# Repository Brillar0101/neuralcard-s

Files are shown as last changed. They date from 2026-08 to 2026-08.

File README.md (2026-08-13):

# NeuralCard







A business card that runs a neural network.

> This is the sponsorship build, a fork of
> [NeuralCard](https://github.com/Brillar0101/NeuralCard) prepared for assembly by
> PCBWay. The BOM has been rewritten from JLCPCB and LCSC part codes into
> manufacturer part numbers PCBWay can quote, with approved alternates where a swap
> is safe and do-not-substitute rules where it is not. Every part in the schematic
> and the board now carries `Alt MPN`, `Alt Mfr`, and `Sourcing` fields alongside
> the existing MPN. See [`docs/SOURCING.md`](docs/SOURCING.md) for the reasoning and
> [`fab/BOM_PCBWay.csv`](fab/BOM_PCBWay.csv) for the order-ready BOM. No copper
> changed, and DRC and ERC still pass clean.

It is a credit-card-sized PCB, 85.6 by 54 mm, carrying an ESP32-S3, a 6-axis
IMU, and 24 LEDs laid out as the network it actually runs: 6 input neurons,
8 hidden, 10 output. You hold the card, draw a digit in the air, and the LEDs
light with the real activations as inference runs. Brightest output neuron
wins.

The front artwork is the network diagram. The synapse lines are drawn at three
stroke weights, the way a trained model's weights differ. There is also an NFC
tag with a coil antenna etched into the copper, so tapping a phone opens
[princetekki.com/card](https://www.princetekki.com/card) and offers a vCard.
That works with a dead battery, or no battery at all, because the phone's own
field powers the tag.

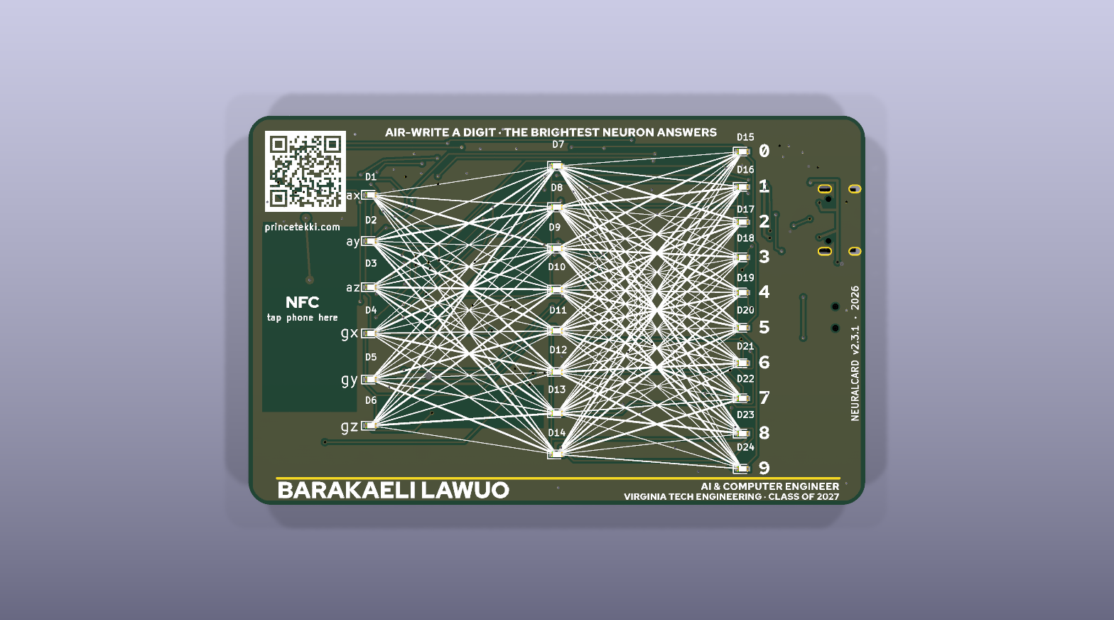
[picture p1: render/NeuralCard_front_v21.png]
front

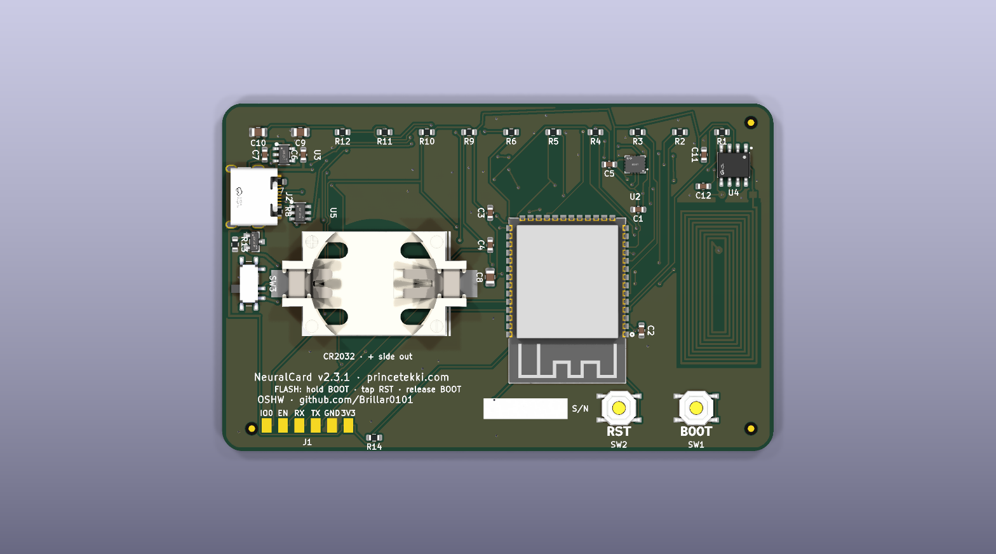
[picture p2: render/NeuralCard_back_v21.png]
back


## Repository layout

| Path | What's in it |
|---|---|
| `hardware/` | KiCad 10 project: schematic, board, custom symbol and footprint libraries, 3D models |
| `fab/` | Manufacturing outputs: gerber zip, drill files, pick-and-place, and two BOMs: `BOM_PCBWay.csv` (MPN-based, for this build) and `BOM_JLCPCB.csv` (upstream, LCSC codes) |
| `firmware/` | ESP-IDF project. Charlieplex driver, IMU driver, gesture recorder. Builds today. |
| `docs/` | Design rationale, component sourcing, datasheet findings, DRC history, audits, FAQ |
| `render/` | The board renders used above |
| `CHANGELOG.md` | Revision history, newest first |

Start with [`docs/DESIGN.md`](docs/DESIGN.md) for why the board is shaped the
way it is, [`docs/FAQ.md`](docs/FAQ.md) for the questions people actually ask,
and [`docs/drc/README.md`](docs/drc/README.md) for the verification trail.

## Hardware

An ESP32-S3-WROOM-1-N8R2 does the thinking and runs the inference. An
LSM6DS3TR-C accelerometer and gyro sits on I2C, and its six axes map one to one
onto the six input neurons. The 24 red LEDs are charlieplexed across 6 GPIO
with software PWM for the glow.

For the business-card half there is an ST25DV04K dynamic NFC tag with a 9-turn
coil in the copper, tuned by a single external cap (C12) against the chip's
internal capacitance.

USB-C arrived in v2.3. The S3 has native USB, so a plain cable flashes the
board and gives a serial console without an adapter. A USBLC6-2SC6 protects the
data pair.

Power comes from either a CR2032 through a real slide switch (SW3) or USB 5 V
through an ME6211 LDO. A P-FET (Q1) disconnects the cell whenever USB is
present, so the board can never try to charge a cell that is not rechargeable.

Two layers, ground poured on both sides and stitched. Every net is one
connected cluster.

## How it's wired

Power first. Two sources that can never fight each other.

```mermaid
flowchart LR
    USB["USB-C · J2<br/>5 V VBUS"] --> LDO["U3 · ME6211<br/>3.3 V LDO"]
    BT1["BT1<br/>CR2032 · 3.0 V"] -->|VBAT| SW3{{"SW3 · MSK12C02<br/>SPDT slide"}}
    SW3 -->|"ON"| Q1{{"Q1 · AO3401A<br/>P-FET isolation"}}
    SW3 -.->|"OFF"| NC(["open throw"])
    LDO --> RAIL[["+3V3 rail"]]
    LDO -.->|"VBUS present<br/>gates the cell off"| Q1
    Q1 --> RAIL
    RAIL --> U1["ESP32-S3"]
    RAIL --> U2["LSM6DS3TR-C"]
    RAIL --> U4["ST25DV04K"]
    RAIL --> LEDS["24 LEDs<br/>charlieplexed"]

    classDef src fill:#F0AB00,stroke:#795600,color:#151515
    classDef sw fill:#0066CC,stroke:#003366,color:#FFFFFF
    classDef rail fill:#009596,stroke:#005F60,color:#FFFFFF
    classDef load fill:#F0F0F0,stroke:#8A8D90,color:#151515
    classDef off fill:#FFFFFF,stroke:#C9190B,color:#C9190B,stroke-dasharray:4 3
    class USB,BT1 src
    class SW3,Q1,LDO sw
    class RAIL rail
    class U1,U2,U4,LEDS load
    class NC off
```

Then data. USB-C carries both power and programming. NFC is independent of
both and needs no power of its own.

```mermaid
flowchart LR
    HOST(["laptop"]) -->|"USB-C · D+/D-"| ESD["U5 · USBLC6<br/>ESD array"]
    ESD -->|"native USB-Serial-JTAG"| U1["ESP32-S3"]
    U1 <-->|I2C| U2["IMU"]
    U1 <-->|I2C| U4["NFC tag"]
    U2 -.->|"motion interrupt"| U1
    U4 -.->|"field-detect GPO"| U1
    PHONE(["phone"]) -.->|"13.56 MHz field<br/>powers the tag"| U4
    U1 --> LEDS["24 LEDs"]

    classDef ext fill:#F0AB00,stroke:#795600,color:#151515
    classDef chip fill:#0066CC,stroke:#003366,color:#FFFFFF
    classDef out fill:#3E8635,stroke:#1F4D19,color:#FFFFFF
    class HOST,PHONE ext
    class ESD,U1,U2,U4 chip
    class LEDS out
```

And inference. The six IMU axes feed the six input neurons, and the LEDs at
each node light with the real activations as the network runs.

```mermaid
flowchart LR
    IMU["LSM6DS3TR-C<br/>ax ay az · gx gy gz"] --> IN["INPUT<br/><b>6 neurons</b>"]
    IN --> HID["HIDDEN<br/><b>8 neurons</b>"]
    HID --> OUT["OUTPUT<br/><b>10 neurons</b><br/>digits 0-9"]
    OUT --> GUESS(["brightest neuron<br/>= the guess"])

    classDef sensor fill:#F0AB00,stroke:#795600,color:#151515
    classDef layer fill:#0066CC,stroke:#003366,color:#FFFFFF
    classDef out fill:#5752D1,stroke:#2A265F,color:#FFFFFF
    classDef result fill:#3E8635,stroke:#1F4D19,color:#FFFFFF
    class IMU sensor
    class IN,HID layer
    class OUT out
    class GUESS result
```

All 24 LEDs run from 6 GPIO by charlieplexing. That is why there are 6
current-limiting resistors rather than 24, and why the display works on a coin
cell at all: only one LED is ever actually lit.

## Firmware

`firmware/` is an ESP-IDF project that builds today. It has the charlieplex
driver, with the LED-to-pin mapping extracted from the board netlist rather
than guessed, the LSM6DS3 driver, and a motion-triggered gesture recorder that
prints labelled CSV over the USB-C console. That recorder is how you build a
training set.

```
cd firmware && idf.py set-target esp32s3 && idf.py build && idf.py flash monitor
```

The neural network itself is deliberately not in the repo yet: it has to be
trained on gestures recorded from real hands, which needs assembled boards.
See [`firmware/README.md`](firmware/README.md).

## Ordering

Everything a fab needs is in `fab/`: `NeuralCard_gerbers.zip` (gerbers +
drill), `NeuralCard-cpl.csv` (placements), and a BOM. Use
`BOM_PCBWay.csv` for this build, which carries manufacturer part numbers,
approved alternates, and per-line substitution rules. `BOM_JLCPCB.csv` is the
upstream file and is keyed to LCSC codes instead.

Build spec: 2 layers, 1.6 mm thickness, green soldermask, HASL. That is the
cheap prototype configuration, currently about $2 for five boards.

Two finish options are worth knowing about if you ever make a batch to hand
out. At 0.8 mm the board feels like a card instead of a circuit board. With
ENIG, the hairline under the name comes out gold, since it is a mask opening
over the ground pour and plates with whatever finish you pick. Both cost more.
Neither changes the gerbers, so they are order-time choices.

**Two build routes:**

Hand assembly means ordering bare boards plus a solder-paste stencil and
buying parts from LCSC. It is the cheapest route, and the stencil is what makes
the LGA-14 IMU tractable with hot air.

Factory assembly means turnkey PCBA on both sides. It adds roughly $100 of fixed
setup and feeder cost at a typical prototype house, so it only pays off around 30
boards or more. This build is being assembled by PCBWay under sponsorship, so see
[`docs/SOURCING.md`](docs/SOURCING.md) for how the parts are actually bought.

Two BOM notes. C12, the NFC tuning cap, ships as 68 pF and should be retuned
against the coil once it exists. Read range is the practical test. The NFC chip
is ST25DV04KC-IE6S3, which is the active part. The older ST25DV04K-IER6S3 is
marked not recommended for new designs but is still widely stocked, and it is
listed as the approved fallback: same package, same pinout, same function.

## Status

The hardware is done and verified at v2.3.1: DRC reports 0 violations and 0
unconnected, ERC is clean, every net is a single connected cluster, and the
footprints have been checked against manufacturer datasheets. It has never been
fabricated. These files would produce the first physical boards.

The firmware scaffold builds. Drivers and gesture capture work. The trained
model is the remaining piece, and it needs assembled boards before it can
exist.

So today the card is a very elaborate NFC business card, and that part works
the moment the tag is programmed.

## License

CERN-OHL-P v2. See [LICENSE](LICENSE). Do whatever you want with it,
attribution appreciated.

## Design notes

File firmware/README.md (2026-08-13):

# NeuralCard firmware

Firmware for the v2.3 board. Nothing here is trained. The network is a
pretrained MNIST CNN taken off the shelf, and the work is in getting a digit
written in the air to look enough like an MNIST digit for it to read.

What works today:

- Charlieplex driver for all 24 LEDs, 8 brightness levels, mapping extracted
  from the board netlist (D1-D24 to CP pin pairs)
- LSM6DS3 driver over I2C (SDA=IO8, SCL=IO17, addr 0x6B)
- Air-writing capture, stroke rendering, and digit classification
- Gesture recorder, motion-triggered capture printed as CSV over the console
- Boot self-test: LED sweep and IMU WHO_AM_I check

Builds for esp32s3 at 255 KB, leaving 76% of the app partition free, and uses
about a third of DIRAM.

## Why there is no training step

The board's classifier is `mnist-8` from the ONNX Model Zoo, published by the
ONNX project under the MIT licence. It is a 5,998 parameter CNN:

    input   1 x 28 x 28, 0..1
    conv1   8 filters 5x5, pad 2  -> relu -> maxpool 2x2 stride 2
    conv2   16 filters 5x5, pad 2 -> relu -> maxpool 3x3 stride 3
    fc      256 -> 10 logits

That is 23.4 KB of float32 weights, small enough to compile straight into the
binary as a C array. `tools/export_mnist_weights.py` downloads the ONNX file
and writes `main/mnist_weights.h`. The forward pass in `main/nn.c` is written
longhand, so there is no inference runtime to port and nothing to link.

Measured, not assumed: `nn.c` scores 98.9% on all 10,000 MNIST test digits when
compiled on a host and run against the real test set, matching the reference
implementation prediction for prediction.

## How air-writing becomes an MNIST digit

`main/canvas.c` integrates the gyro into angular displacement and treats that
as pen position: yaw sweeps the pen left and right, pitch sweeps it up and
down. Roll is ignored, since twisting the card carries no position.

Integrating the gyro is a deliberate choice. Tracking translation instead would
mean double integrating the accelerometer, and that drifts quadratically, so a
one second gesture smears into nothing. Angular displacement integrates once,
so drift grows linearly and stays usable across the couple of seconds a digit
takes to draw.

The stroke is then framed the way MNIST itself is framed, because the network
has only ever seen digits positioned that way: scale the longer side of the
bounding box into a 20x20 box preserving aspect ratio, rasterise a soft-edged
polyline, then shift the result so the ink's centre of mass sits at the centre
of the 28x28 field.

Gyro bias changes with temperature, so it is measured fresh from 50 still
samples immediately before every stroke rather than calibrated once.

## What to actually expect

Two things have been measured and one has not.

Measured: the classifier is right 98.9% of the time on real MNIST. Measured:
the pipeline survives sensor noise. Feeding synthetic strokes through
`canvas.c` and `nn.c` with up to 20 deg/s of added gyro noise and 2 deg/s of
bias error still reads 95% to 100% of them correctly, so sensor quality is not
the limiting factor.

Not measured, and this is the real question: whether a digit drawn by a human
hand holding a card produces a shape the model recognises. Synthetic strokes
are idealised. Real ones will not be. Expect this to be the part that needs
tuning on hardware, and expect it to be worse than the numbers above.

Two known structural problems, both inherent to writing in the air rather than
faults in the model:

There is no pen lift in the air. A 4, 5, or 7 written with a separate stroke
becomes one connected scribble, which is not what MNIST contains. Writing those
digits in a single stroke works better.

The drawing plane is whatever the wrist decides. A digit written on a tilted
plane arrives sheared. Holding the card square to the body helps.

If the shape gap turns out too wide, the honest fixes stay training-free: tune
the stroke thickness and framing in `canvas.c`, or reject low-confidence reads
rather than guessing. The gesture recorder stays in the firmware so the gap can
be measured on real hardware instead of argued about.

## Build and flash

Requires ESP-IDF v5.x (`idf.py` on PATH, target esp32s3).

    cd firmware
    idf.py set-target esp32s3
    idf.py build
    idf.py flash monitor        # plain USB-C cable, no adapter

First flash of a blank board: hold BOOT, tap RST, release BOOT (printed on
the silk), then run the flash command.

To regenerate the weights header from the published model:

    pip install onnx numpy
    python3 tools/export_mnist_weights.py

## Serial commands

| Key | Action |
|---|---|
| `w` | air-write a digit and classify it |
| `p` | print the last stroke the network was shown, as ASCII art |
| `t` | LED sweep test |
| `s` | stream raw IMU CSV (any key stops) |
| `0`-`9` | record one gesture labelled with that digit |

`p` is the debugging tool that matters. When a digit reads wrong, it shows
whether the network saw a malformed shape or simply misjudged a good one.

## What the LEDs show

| LEDs | Row | Shows |
|---|---|---|
| D1-D6 | input | the six live IMU axes while you write |
| D7-D15 | hidden | pooled conv2 features from the classified stroke |
| D16-D24 | output | the ten class probabilities, brightest wins |

The hidden row is a readout, not part of the classification. The real second
convolution has 16 channels, and they are averaged down in pairs to fit the
eight LEDs the board has.

## One thing to verify on first light-up

`cp_set_outputs()` assumes D16-D24 are the output-column LEDs beside the 0-9
silk labels in order. The netlist cannot confirm visual order, so check it
against the physical board and permute the mapping if needed.

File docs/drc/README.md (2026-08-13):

# DRC baselines: branch fix/footprints-from-datasheets, board unmodified

Captured before any footprint change reached the board. KiCad embeds footprints in
the.kicad_pcb, so library edits do not alter these until 'Update Footprints from
Library' is run. Diff against these afterwards.

| Run | Violations | Unconnected | Parity |
|---|---|---|---|
| baseline-default.rpt (project as configured) | 0 | 5 | not checked |
| baseline-parity.rpt (--schematic-parity) | 0 | 5 | 165 |
| baseline-all-promoted.rpt (29 classes -> error) | 414 | 5 | not checked |

Constraints at 0.0 in NeuralCard.kicad_pro: min_clearance, min_connection,
min_groove_width, min_silk_clearance, min_track_width, solder_mask_to_copper_clearance.
clearance and track_width sit at severity 'error' and cannot fire against a zero threshold.

kicad-cli 10.0.3. Board at commit 1001fda.

## After footprint update, zone refill and cell keep-out

| Run | Violations | Unconnected | Note |
|---|---|---|---|
| after-footprint-update.rpt | 9 | 5 | broken footprints stopped hiding real defects |
| after-refill-and-cell-keepout.rpt | 5 | 7 | antenna keep-out satisfied; more GND islands exposed |

The antenna `items_not_allowed` violations went to zero, finding B1 is resolved in copper.
Three zone-clearance violations also cleared.

Unconnected rose 5 -> 7 and one via became dangling, at (65.14, 36.75), which is 9.3 mm from
BT1's centre and therefore inside the new cell keep-out. Both are true findings: the ground
plane was partly held together by copper inside the ESP32 antenna area and under the coin
cell. Removing copper that should never have been there exposed how thin the real stitching
is. This is the same defect as B2 (isolated GND islands), now measured more honestly.

Still outstanding and unaffected by any of the above: six constraints at 0.0 in
NeuralCard.kicad_pro, so `clearance` and `track_width` remain unenforceable; and the 29
suppressed severity classes hiding 414 violations.

## After real fab constraints and a selective severity policy

`after-real-constraints.rpt`, **40 violations, 7 unconnected.** This is the first honest
number this board has produced.

Constraints set from JLCPCB's published 2-layer 1oz process (jlcpcb.com/capabilities):
min_clearance 0.0 -> 0.10, min_track_width 0.0 -> 0.10, min_connection 0.0 -> 0.10,
min_hole_to_hole 0.2 -> 0.45 (was looser than the fab allows), min_text_thickness
0.08 -> 0.15 (their minimum printable line width).

Setting constraints alone changed nothing, because the severities were suppressed too.
Both layers had to be lifted. Severities restored: missing_courtyard, footprint_type_mismatch,
extra_footprint, missing_footprint to error; text_thickness, text_height to warning.

Deliberately left at ignore, with reason: silk_over_copper and silk_overlap. These are 398
of the 438 violations and they are the front-face neural-network artwork - a design decision
by someone who looked, not negligence. Suppressing them at class level is defensible here
because per-object suppression across 398 items is impractical. Recorded so the choice is
visible rather than silent.

footprint_type_mismatch now reports 0: both footprints carrying attr through_hole on all-SMD
parts were corrected.

| Class | Count | Nature |
|---|---|---|
| text_thickness | 28 | board's own labels - RST, S/N, ax/ay/az/gx/gy/gz, OSHW mark - thinner than 0.15mm |
| unconnected_items | 7 | isolated GND islands |
| text_height | 6 | J1 pad labels at 0.7mm |
| courtyards_overlap | 2 | C2 against U1 |
| clearance | 2 | U4 pads vs SDA/SCL at 0.190-0.198mm |
| via_dangling | 1 | GND via under the coin cell, inside the new keep-out |
| missing_courtyard | 1 | ProgPads_1x6 (J1) |

JLCPCB also publishes a 1.0mm minimum silkscreen text height; min_text_height is left at 0.8
pending a decision, since raising it would flag most of the board's labelling.

## After GND stitching

`after-gnd-stitching.rpt`, **40 violations, 3 unconnected.** Four stitching vias added,
0.6/0.3 mm to match the Default net class. No new violations: the count is unchanged and
only `unconnected_items` moved, 7 -> 3.

GND groups went 8 -> 4; the main plane grew 4,170 -> 5,245 mm2.

Connected to the main plane:
- **U1.41, the ESP32's own ground/thermal pad (9 sub-pads)** - via at (39.025, 37.369)
- BT1.2, C8.2, C4.2 - via at (47.298, 10.005)

Merged into the top-edge cluster but still not reaching main:
- U4.4 (NFC ground) - via at (7.758, 6.026)
- C11.2 - via at (10.806, 5.734)

### What a via cannot fix, and why

Three groups remain, stranding U2.6/U2.7 (the IMU's only grounds), C1.2, C5.2, C2.2 and the
NFC ground now chained to them. **None has a via site**: there is no point where the island's
copper on one layer sits over main-plane copper on the other. A via joins layers at a point;
it cannot bridge a gap that exists on both layers at once.

All of them lie in the top-edge strip, y 4.2-22, which is the region fragmented by the ~60 mm
copper-free band at y 3.4-5.0 running x 15-80 on both layers - the slot cut by the signal
bundle feeding the LED resistor row. That band is also why 94% of IMU_INT, 88% of SDA and 82%
of SCL run with no reference copper beneath them.

So the remaining three are one defect, not three: the plane is severed across the top of the
board. Fixing it is a routing change - move the LED resistor bundle so the pour can close -
not a stitching job. Recorded rather than forced.

## After USB power routing (inline, direct)

after-usb-power-routing.rpt - 41 violations, 13 unconnected.

Power nets routed directly via the pcbnew API, geometry-queried per segment, DRC-iterated
on a copy through six revisions: VBUS (J2 both pads -> F.Cu trunk over the phase-1 +3V3
wall -> LDO, C6, U5, Q1 gate, R13), +3V3 (U3.5 -> C9/C10 rail tie -> C7), VBAT_SW
(SW3.3 -> F.Cu hop over the VBAT feed -> Q1 source). R8 rotated 90 so CC2 can enter
axially. J2 given a 0.09mm local clearance - its 0.5mm-pitch pads violate the 0.2 class
rule among themselves; physical gap stays at JLCPCB's published 0.1 minimum.

Delta vs 40-violation baseline: +1 footprint_type_mismatch on J2, accepted with reason:
hybrid SMD connector with PTH shell anchors; attr stays smd so the CPL keeps it.
Unconnected 13 = 3 pre-existing islands + 10 ratsnest gaps of the unrouted USB_DP/USB_DM
pair. U1 pads 13/14 now carry USB_DM/USB_DP (were unconnected- placeholders).

REMAINING: the DP/DM differential pair. USB-C interleaves the A/B pins (B7 DM, A6 DP,
A7 DM, B6 DP at 0.5mm pitch) so pairing them to U5 requires F.Cu via crossings, and the
45mm run to U1 pins 13/14 needs the lane plan: DP y16.05 / DM staggered, turn columns
west of U1's left pad column, entries from west/north. Corridor analysis is in the git
history of this file's session notes.

## After USB data PHY routing

after-usb-phy-routing.rpt - 41 violations (baseline + accepted J2 attr), 7 unconnected.

DP/DM routed from the connector through the ESD array. The USB-C interleave (B7-DM,
A6-DP, A7-DM, B6-DP at 0.5mm pitch) is topologically unroutable on one layer; resolved
with a compact DM dogbone east of the pad column (the NPTHs at y11.6/17.4 are 2mm away,
so the space behind the pads is usable) and an F.Cu via hop for A6 into B6's lane on
the west. DM crosses the DP U5 bridge on F.Cu. VBUS's U5 feed moved to F.Cu via-in-pad
to clear the west corridor.

REMAINING: U5 -> U1 (pins 13/14), ~48mm. The y16-18 corridor is the charlieplex highway
(CP1-6, CHX*, NFC_GPO, EN, +3V3 all live there - a first attempt drew 80+ violations
and was dropped on evidence). Needs its own corridor study; candidates: F.Cu lane, or
B.Cu along y12-13 north of the highway.

### U5 -> U1 corridor study, attempt 2 (F.Cu lanes): failed on evidence

Straight F.Cu lanes at y16.05/17.95 drew 77 USB-involved violations. The assumption
that F.Cu is empty is false: CP2 and CP4 route on F.Cu (the charlieplex uses both
layers), a CP4 via sits at (21.60, 20.44) - touching the only clean B.Cu entry to
U1 pin 13 - and the VBUS F.Cu riser at x71.6 blocks via placement at the U5 end.

Conclusion: no free corridor exists on either layer. The route requires either
(a) threading between individual charlieplex tracks with a full obstacle map of
the y12-22 band on both layers, or (b) first rerouting 2-3 CP tracks to open a
lane - option (b) is likely cheaper. Both need a dedicated session. The board is
committed clean at f393dd8 with the PHY section done and these two nets open.

## After DP/DM completion: USB fully routed

`after-usb-dpdm-complete.rpt` - **41 violations, 7 unconnected. Exact parity with the
pre-USB baseline: the entire USB-C addition costs zero new DRC items.**

Option (b) from the corridor conclusion, executed. Three charlieplex edits opened the lane:

- **CHX6** dipped south of the U1 pad row: its F.Cu horizontal at y17.97 crossed the only
  legal via window; redrawn through y16.5/16.85 with a short B.Cu bridge, clear of the
  17.36-18.86 pad band.
- **CHX4** moved off pad 14: its F.Cu approach camped directly over the pad, blocking the
  DM entry; shifted 0.6mm north to y18.75.
- **CP3** via nudged 0.2mm west at (66.27, 7.34) to widen the northern highway.

Then the pair, A* grid-routed at 0.1mm resolution against a clearance-inflated obstacle
map of every foreign net, waypoint-constrained where the free solver would trade legality
for length:

- **USB_DM**: U5 -> U1 pin 13, 75.9mm, 8 vias. Funnel out of the connector pocket, north
  highway at y8.3 on F.Cu (parts are on the back, so F crosses the pad rows freely), west
  descent at x40, under-row approach into the pad from the south.
- **USB_DP**: U5 -> U1 pin 14, 100.1mm, 10 vias. Free-solved; threads the razor passages
  between the four parallel charlieplex diagonals.
- **VBUS**: U3 pad 1 -> pad 3 repair, 3.3mm, closing the last power gap.

Skew DM 75.9 vs DP 100.1mm is irrelevant at USB full-speed (12 Mbps): 24mm is ~130ps
against a 52ns bit half-period. Impedance is likewise uncontrolled and fine at FS.

Unconnected 7 = the 3 pre-existing GND islands (6 zone pairings) + the orphaned +3V3
fragment at (81.35, 19.4). The fragment predates this work and sits between J2's shell
anchors and the VBUS runs, where no legal lane exists on either layer at current
constraints; left recorded, not forced.

## After GND island bridges

`after-gnd-island-bridges.rpt` - **40 violations, 4 unconnected. One below the pre-USB
baseline: the dangling stitching via under the coin cell is gone.**

The island bookkeeping turned out optimistic. Walking the connectivity database pad by pad
showed **six** disconnected GND groups, not three: the earlier count treated
{BT1.2, C3.2, C4.2, C8.2} as main-plane when it was its own cluster, and C7.2 and C2.2
had each been stranded by the USB power routing slicing the pour around U3 and J2.

Three bridges routed, same A* grid method as the USB pair:

- **C7.2 -> C9.2**, 5.5mm, 2 vias - reconnects the LDO output cap ground.
- **C8.2 -> U1.41**, 44.3mm, 4 vias - ties the battery cluster (BT1, C3, C4, C8) into the
  ESP32 thermal pad, detouring around the charlieplex matrix.
- **C2.2 -> U1.1**, 18.1mm, 4 vias - down the alley west of U1's pad column.

Main plane: 22 -> 28 pads. Also fixed en route: J2's footprint carried a 0.09mm local
clearance override, below JLCPCB's 0.10 board minimum. It never fired because the pour
behind J2 used to be discarded as an isolated island; the C7 bridge revived that copper
and DRC caught it. Override raised to 0.10 - the connector's own pad-to-pad gaps measure
0.1000/0.1002, exactly at the fab's limit, so 0.10 is the only value that passes both ways.

### Three islands remain, each provably unroutable without moving signals

Exhaustive both-layer flood-fill from each island (via hops included) confirms no legal
0.2mm lane exists at current clearances:

- **{U2.6, U2.7}** - the IMU's only grounds sit in a sealed pocket: the LGA fanout walls
  it north and east, SDA/SCL wall it south, the NFC region west.
- **{C11.2, U4.4}** - the NFC ground chain is enclosed by the antenna coil and the LED
  resistor bundle on both layers.
- **{C1.2, C5.2}** - hemmed in by CP2/CP4's horizontals, the charlieplex diagonals and
  the new USB entries; the 5mm hop to C2.2 has no lane on either layer.

All three need the same cure the corridor study prescribed: shift the LED resistor bundle
(and for U2, the IMU fanout) so the pour can close. That is a layout change with RF and
matrix implications, out of scope for the USB-C branch. Unconnected 4 = these 3 island
edges + the orphaned +3V3 fragment behind J2.

## Zero

`zero-violations.rpt` - **0 violations, 0 unconnected. ERC: 0 errors, 0 warnings.**
Every net on the board is a single connected cluster, including GND (42 pads, one plane).

What it took, beyond the USB work above:

**Silk text (34).** Three separate root causes. The J1 pad labels were under the 0.8mm
height minimum - raised. The stroke-font texts were under 0.15mm - thickened. The
TrueType texts (Red Hat Display/Mono/Text at SemiBold) genuinely render strokes thinner
than JLCPCB's 0.15mm printable minimum at small sizes; DRC measures the cached glyph
polygons, so no pen-width setting can fix them. Weights raised to Bold/Black board-wide,
the six IMU-axis labels and headline texts rescaled, and twelve small functional labels
(instructions, URLs) converted to the KiCad stroke font, which is guaranteed printable.
Fontconfig trap recorded: the face string must be the fontconfig family name -
"Red Hat Mono" plus the bold flag, not "Red Hat Mono Bold", which silently substitutes
Andale Mono.

**Clearance shaves (2).** NFC_ANT_B and SCL sat 2-10 microns inside the 0.2mm class
clearance at U4's pads. Both nudged with 45-degree joins preserved.

**Courtyards (3).** C1-C6 carried 0.65mm courtyard margins - two and a half times the
IPC norm for an 0603 - which is what actually collided with U1's module courtyard;
trimmed to 0.30/0.25mm. J1 had no courtyard at all; drawn from its pad extents plus
0.25mm.

**J2 type mismatch (1).** Excluded per-item in the project file with the reason inline:
hybrid SMD connector with PTH shell anchors, attr stays smd so the CPL keeps it.

**The +3V3 fragment.** Unroutable for two sessions - because the router's grid ended at
x=80 and the board ends at x=85.65. With the full board in the grid it routed in one
pass: 12.4mm, zero vias, around J2's east side.

**The three GND islands.** The top-edge seal was three tracks: SDA and NFC_GPO on F.Cu
plus the +3V3 north rail on B.Cu, jointly closing y3.1-4.7 across the whole board while
the top 2.5mm of the card sat empty. Both +3V3 horizontals moved into that empty strip,
which opened a B.Cu crossing; the NFC ground chain (67mm), the C1/C5 group (58mm) and
the IMU grounds (18mm) then routed through it to the main plane. The IMU pocket
additionally needed one redundant +3V3 branch deleted - U2 was fed from both sides, and
the west diagonal was the wall; its cap chain re-fed locally (6.4mm).

**ERC.** The one warning was U2's SDO/SA0 strapped to 3V3 - the deliberate I2C address
select. pin_to_pin set to ignore with this note as the reason; it was the only instance.

Fab package regenerated to match: gerbers, drill, and a 61-component CPL including the
USB-C section.

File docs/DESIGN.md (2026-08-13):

# NeuralCard: AI Business Card (Design Spec)

> An ESP32-S3 PCB business card shaped like a neural network. You **air-write a digit (0 to 9)
> holding the card**; an on-device neural net classifies the motion, and the **LEDs at each
> neuron node ripple the real inference**, the brightest output neuron is the recognized digit.

**Owner:** Barakaeli Lawuo, AI & Computer Engineer
**KiCad:** v9 file format, `kicad-cli 10.0.3`.

---

## 1. Form factor (ISO/IEC 7810 ID-1: real credit card)

| Spec | Value |
|---|---|
| Outline | **85.60 mm × 53.98 mm** rounded rectangle |
| Corner radius | **3.18 mm** |
| PCB thickness | **1.6 mm** standard for prototypes; 0.8 mm is the card-like option |
| Layers | 2-layer |
| Assembly | **100% SMD/SMT. Only non-soldered item = the CR2032 coin.** Fab: **PCBWay** (sponsorship build). |

Board outline is on `Edge.Cuts` in `NeuralCard.kicad_pcb` (render-verified).

---

## 0. DESIGN REVISION (v2: USB-C removed)
USB-C was dropped in favor of **6 UART programming pads** (3V3, GND, TX, RX, EN, IO0). This
removed 9 parts (USB-C, USBLC6 ESD, ME6211 LDO, AO3401A P-FET, 2× CC res, gate bleeder, 2× LDO
caps), made the card flatter/cheaper, and **eliminated the routing congestion → 100% auto-routed,
0 DRC violations.** Power is now **coin → +3V3 directly** (also feedable from the prog-pad 3V3
during flashing). LEDs are **red** (bright on a 3 V coin). **47 assembled SMD parts** + the prog
pads (bare copper). Flash once with a USB-serial adapter, then it runs on the coin cell.

## 2. Architecture

- **Compute:** ESP32-S3-WROOM-1-N16R8 (vector/DSP for TinyML; native USB; radio OFF for coin life).
- **Input:** LSM6DS3TR-C 6-axis IMU (air-writing). 6 axes map 1:1 to the 6 input neurons.
- **Display:** 24 LEDs at neuron nodes, charlieplexed from 6 GPIO (software PWM = activation glow).
- **Power:** CR2032 coin + USB-C/LDO with **P-FET automatic source selection** (see §3).
- **Program:** USB-C native (ESP32-S3 built-in USB) + BOOT/RESET tact buttons + USBLC6 ESD.

### Neural-net art topology (the visible layout)
```
 INPUT (6) = IMU axes      HIDDEN (8)        OUTPUT (10) = digits 0-9
  ax ay az gx gy gz   ->   o o o o o o o o  ->  0 1 2 3 4 5 6 7 8 9
```
24 neuron LEDs (D1, D24). Brightest output = the guess. Labeled on silk.

---

## 3. Power architecture (resolved)

```
 USB-C VBUS(5V) ──► ME6211 LDO ──► +3V3 rail ──► ESP32-S3 / IMU / LEDs
                                      ▲
 CR2032 (VCOIN) ──► Q1 AO3401A P-FET ─┘   (S=+3V3, D=VCOIN, G=VBUS, R13 100k bleeder)
```
- USB plugged → VBUS=5 V → gate high → **P-FET OFF**, coin disconnected (no back-charge); LDO powers rail.
- USB absent → R13 pulls VBUS(gate)=0 → **P-FET ON**, coin powers rail at **full 3.0 V (no diode drop)**.
- Radio OFF + bulk/ride-out caps (C8 10µF, C9 22µF, C10 100µF) absorb inference/LED peaks.

### Pin map (as built in schematic: Power + MCU sections)
| Function | Net | GPIO (module pin) |
|---|---|---|
| IMU I²C SDA | SDA | GPIO8 (p12) |
| IMU I²C SCL | SCL | GPIO17 (p10) |
| IMU INT1 | IMU_INT | GPIO18 (p11) |
| Charlieplex lines 1 to 6 | CHX1..6 | GPIO4/5/6/7 (p4 to 7), GPIO15 (p8), GPIO16 (p9) |
| USB D− / D+ | USB_DM / USB_DP | GPIO19 (p13) / GPIO20 (p14) |
| BOOT / RESET | IO0 / EN | GPIO0 (p27)+SW1 / EN (p3)+SW2 |

> GPIO35/36/37 (p28 to 30) reserved for octal PSRAM (N16R8), left unconnected.

---

## 4. BOM
> See [`BOM.md`](./BOM.md) (with LCSC confirm links), [`SOURCING.md`](./SOURCING.md), and
> [`BOM_PCBWay.csv`](../fab/BOM_PCBWay.csv).
> Catalogue-exact footprints in `Parts.pretty`; symbols in `Parts.kicad_sym`.
> 56 placements. LSM6DS3TR-C = JLC Standard-PCBA-only + fixture; blue LEDs are dim on coin
> (swap to red for brightness, same footprint).

---

## 5. Build status (section-by-section, ERC-gated)
1. **Scaffold**, project, board outline, lib tables, datasheets, BOM.
2. **Power**, coin + USB-C/LDO + P-FET auto-select + caps. **ERC: 0 errors.**
3. **MCU core**, ESP32-S3 module, decoupling, EN/BOOT buttons, native USB + USBLC6 ESD, USB-C. **ERC: 0 errors.**
4. **IMU**, LSM6DS3TR-C on I²C (addr 0x6A), 4.7k pull-ups, INT1→GPIO18. **ERC: 0 errors.**
5. **Neuron LEDs**, 24 LEDs charlieplexed on 6 GPIO (CHX1-6→R1-6→CP1-6 nodes). **ERC: 0 errors.**
6. **PCB layout**, front = neural-net art (LED neurons + silk synapses + ax/ay/az/gx/gy/gz +
   digits 0-9 + name + QR), back = all parts. GND pour both layers + stitching vias.
   **Routed via Freerouting (headless): 465 tracks, 57 vias, 99% complete, 0 shorts/crossings.**
   - ⬜ Remaining manual finish (~5 min in GUI): USB-C connector fan-out (~2-3 jumpers:
     CC2, USBC_DP pad-pair) + a few GND pour islands. Autorouters + humans both fight USB-C fan-out.
7. **Fab outputs**, `fab/NeuralCard_gerbers.zip` (Gerbers + drill), `fab/NeuralCard-cpl.csv`
   (pick & place), `BOM_JLCPCB.csv`. The 9 DRC items are internal to the USB-C footprint
   (0.5 mm pitch), standard and JLC-manufacturable.

**Full schematic complete: 54 components, ERC 0 errors** (remaining 41 warnings are benign
`pin_to_pin` "unspecified pin-type" notices inherent to imported catalogue symbols).
Counts verified 2026-08-02 against `kicad-cli sch erc` / `sch export netlist`; SW3 is
included. Note 54 schematic components vs 52 CPL placements, ANT1 and J1 are the
difference, both bare copper and excluded from BOM/CPL.

---

## 6. Firmware sketch (out of PCB scope)
Boot → radio OFF → init IMU FIFO → idle, wake on IMU INT → on "write" gesture capture ~1 s of
6-axis motion → normalize → MLP/1D-CNN → 10-way softmax → drive output neuron LEDs by probability;
ripple input→hidden→output. Model trained off-device, int8-quantized, stored in flash.

---

## 8. NFC tap-to-share (v2.1)

**ST25DV04KC-IE6S3** (U4, SO-8, LCSC C3304276) on the shared I2C bus
(addr 0x53 user / 0x57 system, no clash with IMU 0x6A). GPO (open-drain
field-detect, R14 100k pull-up) -> **GPIO21** (module pin 23): phone tap can
wake the ESP32 for an LED ripple. C11 100nF decoupling. V_EH unused.

**Antenna:** 9-turn rectangular spiral on B.Cu, outer 12x24.5mm at
x[2.5,14.5] y[16,40.5] (left-middle, under the input-LED column area),
0.3mm track / 0.3mm gap. The net-tie footprint
`NeuralCard:NFC_Antenna_13x24` bridges
NFC_ANT_A/NFC_ANT_B legally; inner terminal escapes on F.Cu between two
0.3mm-drill TH pads. Front silk marks the tap zone ("NFC / tap phone here").

**Tuning:** coil ~1.5uH (Mohan approx) + 28.5pF chip-internal + ~3pF
parasitics -> **C12 62pF NP0** across AC0/AC1 => ~13.6 MHz pre-fab.
Verify on the fab'd board with a VNA; trim C12 within 56 to 68pF.

**Rule areas** (both layers) over the coil: no pour, no tracks, no vias,
pads and footprint copper exempt, so the coil itself is legal and the
autorouter/GND pour stay out of the field.

**Pour handling:** orphan GND pour
fragments are tied with vias and <3mm2 slivers purged. GND pour local
clearance raised 0.2 -> 0.3mm (>= 0.25 hole-to-copper rule).

**Layout shifts vs v2:** stitching vias at (2.6,27), (2.6,42), (5,51)
removed (coil/NFC pocket); U4/C11 top-left beside IMU; C12 at the coil
feed; NFC content plan: NDEF URI -> portfolio /card page (vCard download);
QR on front silk should encode the same URL.

**Status:** re-routed 100% (freerouting, 0 unrouted), **DRC 0 violations**;
5 cosmetic same-net GND-pour fragment notices remain (every GND pad is
track-routed; fragments are redundant copper). Fab outputs regenerated.

### BOM verification note (v2.1, JLCPCB live check)
All LCSC IDs verified against JLCPCB part pages. Three v2-era mismatches fixed:
C2913204 is the **N8R2** module (BOM said N16R8), fine for this design (PSRAM
pins NC, int8 MLP fits 8MB flash easily); C8's old ID (C5674) was a 22uF part,
now C15850 (true 10uF); C10's old ID (C15850) was 10uF, not 100uF, no basic
100uF exists in 0805, so C10 is now 22uF (C45783), total bulk ~54uF. If more
ride-out is wanted, move C10 to a 1206 100uF in the next rev. ESP32 + IMU are
Standard-PCBA-only parts, so the board assembles as Standard regardless of the
NFC chip being Economic-capable.

### Power-button behavior (firmware spec, no hardware change)
SW1/GPIO0 doubles as the power button: **long-press = off** (deep sleep,
motion-wake disabled, only EXT0/GPIO0 button wake armed, ~7-10uA, years on
the coin, comparable to CR2032 self-discharge); **press = on** (boot, arm
IMU wake-on-motion, wake ripple). Short press while on = user button
(replay last inference / mode cycle). SW2 stays hard reset. NFC keeps
working while "off" (RF-field powered). A hard-off latch IC was considered
and rejected: saves nothing vs battery self-discharge, costs parts + reroute.

## 9. Hardware power switch: SW3 (v2.2)

**SHOU HAN MSK12C02** (SW3, LCSC C431540), an SPDT slide switch in series between the coin
cell and the `+3V3` rail. Physical on/off, independent of the SW1/GPIO0 firmware deep-sleep
behavior in §8, that spec still stands; SW3 supplements it with a true hard cutoff.

```
 BT1 CR2032 (+) ──► VBAT ──► SW3 pad 2 (common pole)
                              ├── pad 3 ──► +3V3 rail    (slid ON)
                              └── pad 1 ──► open throw   (slid OFF)
```

| Property | Value |
|---|---|
| Footprint | `Button_Switch_SMD:SW_SPDT_Shouhan_MSK12C02` |
| Body | 8 × 2.8 mm, right-angle actuator |
| Pads | 3 signal + 4 `SH` shield tabs + 2× 0.85 mm NPTH locating holes |
| Placement | 81.4550, -28.0000, Bottom, rotated -90 (v2.2 re-place; was 142.1112, -64.4434) |
| Orientation | Pins inboard toward BT1; actuator faces the right card edge (thumb-reachable) |
| Edge clearance | 1.0 mm courtyard-to-edge (moved 0.546 mm inboard for assembly) |

The four `SH` tabs are **intentionally netless**. They are the retention frame, and the
datasheet does not state that the frame is isolated from the contacts, tying them to GND
risks shorting the coin cell. They still solder down for mechanical retention.

**Schematic symbol:** `Switch:SW_SPDT`, in the POWER section.
KiCad's generic SPDT numbers its common pole **pin 2**, which matches the MSK12C02 pinout
and the pad nets on the board, so the stock symbol is used unmodified.

> **Do not renumber SW3's pins.** Pin 2 is the common pole on `VBAT`, pin 3 the closed
> throw on `+3V3`, pin 1 the open throw (explicit no-connect). Swapping them would short the
> coin cell across the throws. Verified pad-by-pad against `NeuralCard.kicad_pcb`:
> 174 schematic pads vs 173 PCB pads, **0 net mismatches**, Update PCB from Schematic is a
> connectivity no-op. See [`CHANGELOG.md`](../CHANGELOG.md).

---

## 10. Decoupling re-place (v2.2)

The v2.1 board had its decoupling capacitors in the wrong place, not miswired, just
physically distant from the ICs they serve, dealt into two cosmetic edge rows by
list order, with no reference to which IC a cap belonged to.

Measured on the v2.1 board, centroid to centroid:

| IC | v2.1 nearest cap | v2.2 |
|---|---|---|
| U1 ESP32-S3 | **24.8 mm** | 11.4 mm (C3 sits ~2 mm off the module edge) |
| U2 IMU | 10.8 mm (its own C5 was **42 mm** away) | **4.0 mm** |
| U4 NFC | 4.9 mm | 4.9 mm (unchanged) |

At ~0.3 to 0.8 nH of loop inductance per mm, a 100 nF cap 25 mm from the pin it feeds does
essentially nothing at the frequencies that matter. Neither ERC nor DRC can see this, the
connectivity was always correct.

**v2.2 placement.** C1/C2 on the module's left flank, C3/C4/C8 in the corridor between the
module's pad edge (x≈41.1) and BT1's courtyard (x≈47). That corridor is only ~6 mm wide, so
those caps are rotated 90°: a 0603 on its side is 0.8 mm across instead of 1.6 mm. C5 sits
4 mm from the IMU. C9/C10 (22 µF ride-out, not HF decoupling) stay in the top edge row,
keeping them out of the corridor is what let the output-column charlieplex lines route.

**U1 still reads 11.4 mm** to its nearest cap and the detector still flags it. That is an
artefact of centroid-to-centroid measurement against an 18 × 25.5 mm module: any cap beside
the module edge is ≥9 mm from its centre. C3 is ~2 mm from the module edge and close to the
3V3 pin, which is what actually matters.

### Also in v2.2

- **SW3 entered the placement data.** It was added by hand in `b2ccb56`, so any re-place
  would have dropped it to the default centre slot.
- **Part numbers moved into the schematic**, `MPN`, `Manufacturer`, `LCSC` on every
  purchasable component (15/18 lines; ANT1, J1 and C12 are correctly part-less).

### Verification (v2.2)

| | v2.1 | v2.2 |
|---|---|---|
| Routing | 100% | **100%** (freerouting score 995.36, 0 unrouted) |
| Unconnected pads | 0 | **0** (the 7 reported are netless by design: ANT1 escape, SW3's 2 NPTH + 4 shield tabs) |
| Tracks / vias | 465 / 57 | 631 / 79 |
| ERC | 0 errors | 0 errors, 41 warnings |
| DRC clearance/crossing | 0 | 0 |
| GND pour fragments | 5 | **28**: see below |

**Known regression: isolated GND pour islands went from 5 to 28.** These are redundant copper
fragments the stitcher could not reach with a via; every GND pad is track-routed, so this is
cosmetic rather than functional. It is a side effect of the new placement changing the pour
topology; stitching converges there (a second pass adds 0 vias). Worth
revisiting before a large production run, since isolated copper is not ideal for EMC.

---

### NFC/QR destinations (final)
- QR (copper-permanent): **https://www.princetekki.com** (v3, EC-Q, regenerated
  2026-07, old matrix encoded a stale URL and was replaced).
- NFC NDEF (rewritable): **dual-record message**, record 1 is the vCard as
  `text/vcard` (Android routes it straight to Contacts on tap: true direct save),
  record 2 is the URI **https://www.princetekki.com/card?src=nfc** (iPhone ignores
  the vCard in background reading and dispatches the URL to Safari). 255 B of the
  tag's 512 B. Flash with the ST25 App once boards arrive, no firmware needed. Verify both flows on
  real hardware before handing cards out.
- The /card landing page lives in the portfolio repo (CardPage.jsx): vCard 3.0
  download (public/card.vcf, keep in sync with src/config.js), social links,
  and it greets with the drawn digit when ?drew=N is appended by future firmware.

### Typography (v2.1)
Silkscreen uses the site's PatternFly faces (outline fonts, plotted as
polygons): Red Hat Display Bold (name), Red Hat Text SemiBold (title,
instruction), Red Hat Mono SemiBold (digits, axis labels, URL, microtext).
SemiBold keeps small strokes above JLC's 0.15mm silk minimum. Applied
after place/route, BEFORE fab export.
The Red Hat font family must be installed locally for the silkscreen to render (RedHatOfficial/RedHatFont).

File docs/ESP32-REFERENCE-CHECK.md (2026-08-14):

# NeuralCard against the ESP32-S3-WROOM-1 reference schematic

Espressif publishes a reference schematic for the WROOM-1 module. This file walks
it line by line against what NeuralCard actually has, says where the two differ,
and gives a verdict on whether each difference matters.

Everything below was read out of a netlist exported from the current schematic,
not from memory.

## What the reference has, and what we have

| Reference | NeuralCard | Present |
|---|---|---|
| SW1 reset button on EN, R7 10k pull-up, C8 100nF | SW2 on EN, R9 10k pull-up, C4 100nF | yes |
| JP4 "Boot Option", a jumper shorting IO0 to GND | SW1 tact on IO0, R10 10k pull-up | yes |
| JP3 "USB OTG" header carrying USB_D+ and USB_D- | J2 USB-C receptacle, U5 USBLC6 ESD array | yes |
| JP1 UART header, TXD0 and RXD0 | J1 six pad programming header | yes |
| C1 22uF bulk and C3 100nF on the 3V3 rail | C9 and C10 22uF, six 100nF including one 2.8mm from the module | yes |
| Pin 40 GND and pin 41 EPAD tied to ground | both on GND | yes |
| JP2 JTAG header on IO39 to IO42 | not fitted, all four pins free | no |
| X1 32.768kHz crystal, C4 and C7 12pF, R3 and R5 | not fitted | no |
| R4 and R6, 0 ohm in series with USB D+ and D- | wired straight through | no |

The exact connections, for the two that looked missing:

    IO0     U1.27, SW1.1, SW1.3, R10.2, J1.6      SW1 to GND, R10 to +3V3
    EN      U1.3,  SW2.1, SW2.3, R9.2,  C4.1, J1.5
    USB_DP  J2.A6, J2.B6, U1.14, U5.1, U5.6       U1 pin 14 is IO20
    USB_DM  J2.A7, J2.B7, U1.13, U5.3, U5.4       U1 pin 13 is IO19

IO19 and IO20 are the ESP32-S3's native USB pins, so the USB-C connector is wired
to the same peripheral the reference calls USB OTG. The reference breaks it out to
a header because a module evaluation board has no connector of its own. This card
has the connector, which is the same thing one step further along.

## Boot and reset, and the open copper ring idea

The reference draws boot as JP4, a two pin jumper you bridge to hold IO0 low
through reset. NeuralCard uses a momentary tact switch instead. Electrically they
are the same node with the same 10k pull-up. A button is the better choice on a
card someone is holding, because entering download mode is hold BOOT, tap RESET,
release, and that is a one handed action with buttons and a fiddly one with a
jumper and tweezers.

Solder pads, the open copper ring idea, would save two parts and about 1.5mm of
height. They are the right answer on a board that is programmed once at assembly
and never again. They are the wrong answer here, because this card is meant to be
reflashed by whoever is holding it.

Worth knowing either way: on the S3 you rarely touch either control. The built in
USB Serial JTAG peripheral can put the chip into download mode over the USB-C
cable with no buttons pressed at all. SW1 and SW2 are the fallback for when
firmware has crashed the USB stack badly enough that the automatic path fails.
That is also why replacing them with pads would not be fatal, only annoying.

## Is anything genuinely missing worth adding

Three items in the reference are not on this board. None of them should be added.

**JTAG header, IO39 to IO42.** Not necessary. The S3 has a USB Serial JTAG bridge
built into the same D+ and D- lines already routed to the USB-C connector, so you
get JTAG debugging through the cable that is already plugged in. An external JTAG
header only earns its space when you need faster or more reliable debug than the
internal bridge gives, which is a mass production or silicon bring up problem, not
a business card problem. All four pins are still free if that ever changes.

**32.768kHz crystal.** Not necessary, and the reference agrees: every part in that
sub circuit is marked NC, no component. It only buys an accurate real time clock
across deep sleep. This card is awake when powered and does not keep time.

**0 ohm series resistors on USB D+ and D-.** Not necessary. They exist so a
prototype can be cut open for probing or impedance tuning. At USB full speed over
a trace this short, they are ceremony. Leaving them out removes two parts and two
solder joints from the highest speed pair on the board.

## A stale netlist, and why it did not matter as much as it looked

`hardware/NeuralCard.net` was stale. It predated the USB-C work and showed U1 pins
13 and 14 as unconnected, with no USB_DP, USB_DM, VBUS, CC1 or CC2 nets anywhere.
Reading it was what first suggested the USB port might be unwired.

It is regenerated now, and carries all 31 real nets. The refresh added CC1, CC2,
USB_DM, USB_DP, VBAT_SW and VBUS, and lost nothing.

The scare was smaller than it first appeared. `*.net` is in `.gitignore` and the
file has never been tracked, which is correct: a netlist is derived from the
schematic and regenerating it is one command. So nobody cloning this repository
ever saw the stale version, and the board was never wrong either. The only thing
at risk was a local tool, or a person, reading a file that KiCad had not rewritten
since the USB-C section was added.

The lesson worth keeping is to export the netlist fresh before trusting it, rather
than reading whatever happens to be sitting in the working directory.

Checked after regenerating, comparing every pin in the schematic against every pad
on the board: 211 board pads carry nets, with zero net name disagreements and zero
schematic pins without a matching pad. ERC 0 violations, DRC 0 violations and 0
unconnected.

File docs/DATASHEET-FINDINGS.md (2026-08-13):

# Datasheet findings: what changes, and the page that says so

Every row is a change to the board or libraries, traced to the page, table or figure of the
manufacturer datasheet that mandates it. Page numbers are **PDF page numbers** in the file
held in `hardware/datasheets/`, with the document's own section/table/figure number alongside,
because the two rarely agree.

Nothing in this document is engineering opinion. Where a change is a judgement call rather
than a datasheet requirement, it is marked **[judgement]** and the reasoning is given.

**Status: 14 of 14 parts documented.** SW3 is verified against a drawing that exists only as a screenshot, see its provenance warning.

---

## U1: ESP32-S3-WROOM-1-N8R2 (Espressif)

`hardware/datasheets/ESP32-S3-WROOM-1.pdf`, Datasheet v1.8

| # | Change required | Datasheet reference | Current state |
|---|---|---|---|
| U1-1 | **Clear all copper from the antenna keep-out zone, on both layers.** Board coords x 23.0 to 41.0, y 37.36 to 43.39 | **PDF p.10**, §3.1 Pin Layout: diagram labelled "Keepout Zone"; **PDF p.45**, Fig 10.1 Module Dimensions: "Antenna Area", 7.49 mm | F.Cu **84.4 %** copper, B.Cu **81.3 %** copper. No keep-out zone exists. |
| U1-2 | **Set pin electrical types**: pins 1, 2, 40, 41 → `power_in`; pin 3 (EN) → `input`; pins 4 to 39 → `bidirectional` | **PDF p.11**, Table 3-1 Pin Definitions, "Type" column: `P` = power, `I` = input, `I/O/T` = input/output/tristate | All 41 pins are `unspecified` in `Parts.kicad_sym`. ERC electrical checking is off board-wide. |
| U1-3 | Pin numbering and names: **no change needed** | **PDF p.11**, Table 3-1 | Verified: 41 pins, 40 of 41 names match exactly. Pin 41 is named `GND` in the symbol vs `EPAD` in the table: Table 3-1 gives EPAD's Function as "GND", so this is correct and arguably clearer. |
| U1-4 | **Verified 2026-08-07**: EN and boot strapping match the reference design | Espressif reference schematic (WROOM-1 variant) | EN: R9 10 kΩ pull-up to 3V3 + C4 100 nF to GND + SW2 (reset to GND): exactly the datasheet's 10 kΩ/0.1 µF RC. IO0: R10 10 kΩ pull-up + SW1 (boot to GND). GPIO45/46/3 float at their default straps (VDD_SPI = 3.3 V). USB polarity correct: pin 13 IO19 = D− = USB_DM, pin 14 IO20 = D+ = USB_DP, matching J2 A7/B7 = D− and A6/B6 = D+. Deviation from reference: no 499 Ω series on U0TXD and no ESD diode on EN: both belong to the auto-download circuit of a permanent USB-UART bridge; J1 here is passive program pads, so they are optional. |

**Note on variant:** the board uses **WROOM-1** (integrated PCB antenna), not WROOM-1U (external
connector). Datasheet **p.10** states explicitly that WROOM-1U "has no antenna keepout zone."
The keep-out requirement in U1-1 applies *because* this is the -1 variant.

---

## U4: ST25DV04KC-IE6S3 (STMicroelectronics)

`hardware/datasheets/ST25DV04KC.pdf`, DS13519 Rev 8. Footprint
`ST25DV.pretty/SO-8_L4.9-W3.9-P1.27-LS5.9-BL.kicad_mod`

| # | Change required | Datasheet reference | Current state |
|---|---|---|---|
| U4-1 | **Change `(attr through_hole)` to `(attr smd)`** | **PDF p.151**, §10.1 SO8N package information: an SO8N is a gull-wing surface-mount package; all 8 pads in the footprint are already `smd` | `(attr through_hole)` on an all-SMD part. Drives position-file output and PCBA classification: the same failure class as the SW3 rejection. |
| U4-2 | **Extend the courtyard to enclose the pads.** Pads reach y ±3.644; courtyard stops at y ±1.960 | Derived from the land pattern, **PDF p.151**, Fig 85 | Pads sit **1.684 mm outside the courtyard** on both sides. DRC cannot detect encroachment on most of this part's copper. |
| U4-3 | **Add `F.Fab` body outline: 4.9 × 3.9 mm** (D typ × E1 typ) | **PDF p.151**, Table 259 SO8N Mechanical data: D = 4.800/4.900/5.000, E1 = 3.800/3.900/4.000 | No `F.Fab` geometry at all. |
| U4-4 | **Fix the 3D model path** to `${KIPRJMOD}/…` | n/a: repo hygiene, not a datasheet item | `nfc_integration/ST25DV.3dshapes/…`, relative to a directory that does not exist. |
| U4-5 | **[judgement]** Consider redrawing pads to ST's recommendation | **PDF p.151**, Fig 85 SO8N Footprint example: 0.6 mm pad width ×8, 1.27 mm pitch, 6.7 mm outer span, 3.9 mm inner gap (⇒ 1.4 mm pad length) | See table below. Deviates but will function. |

### U4-5 detail: land pattern vs Figure 85

| Dimension | Datasheet (Fig 85) | Footprint | Delta |
|---|---|---|---|
| Pitch | 1.27 mm | 1.27 mm | ✓ |
| Pad width | 0.60 mm | 0.574 mm | −4 % |
| Pad length | 1.40 mm | 1.888 mm | **+35 %** |
| Outer span | 6.70 mm | 7.288 mm | +0.59 mm |
| Inner gap | 3.90 mm | 3.512 mm | −0.39 mm |

**Verdict: functional, not correct.** Pads are longer than ST recommends in both directions.
Outward extension is harmless and aids inspection. Inward extension is the questionable half,
ST puts the inner pad edge flush with the body (E1 = 3.9 mm), and this footprint runs **0.194 mm
under the package on each side**. At 1.27 mm pitch that is unlikely to cause wicking, and the
narrower pad still covers the lead (b = 0.28 to 0.48 mm, **Table 259**). Joints will form.

This is a *deviation from the manufacturer's recommendation that nobody had compared*, not a
defect that stops the board working. Fixing it is the same work as U4-2 and U4-3, so do all
three together if the footprint is redrawn.

---

## SW3: MSK12C02 (SHOU HAN): VERIFIED against the manufacturer drawing

`hardware/datasheets/MSK12C02.pdf` (7-page specification) and
`hardware/datasheets/MSK12C02-outline-drawing.png` (mechanical drawing, from the LCSC
product page, **not** in the PDF).

**No change required.** Every checkable dimension of KiCad's shipped
`Button_Switch_SMD.pretty/SW_SPDT_Shouhan_MSK12C02.kicad_mod` matches the drawing:

| Feature | Drawing | Footprint |
|---|---|---|
| Mounting holes | 2 × Ø0.85, 3.0 mm apart | 2 × Ø0.85 NPTH at (±1.5, 0) |
| Post diameter on the part | Ø0.75 ±0.1 | 0.10 mm clearance in the hole |
| Signal pads | 0.6 × 1.3, spacing **1.5 and 3.0** | −2.25 / 0.75 / 2.25 |
| Shield pads | 1.05 × 0.7, outer 8.4 / inner 6.3 | ±3.675, ±1.1 |

### Two traps recorded, because both cost time

**The non-uniform pin spacing is correct.** 1.5 mm on one side and 3.0 mm on the other looks
like a library error and is not, the drawing dimensions it that way. Do not "fix" it.

**The specification text contradicts the drawing.** §2.4 states "1 pole, 1 throw" and §2.3
says "tactile feedback", and the cover calls the part 轻触开关 (*tactile switch*). The
drawing's 电路图 shows ①②③ plus ④ as shield, unambiguously SPDT. The text sections of that
PDF are a vendor template with the wrong product's content; **the drawing is the authority.**

**Three prongs vs two holes:** the part has **two** Ø0.75 mounting posts, which is what the
two holes are for. The three items that read as vertical prongs in the 3D render are the
signal terminals ①②③, flat 0.15 mm tabs that solder to the surface, per the end view and
the mounting diagram. If the STEP model renders them as vertical pins it misrepresents the
part; cosmetic only, no fabrication consequence.

### Provenance warning

The mechanical drawing exists in this repo **only as a screenshot** of the LCSC product page.
The linked PDF (`lcsc_datasheet_2304140030_SHOU-HAN-MSK12C02_C431540.pdf`) is byte-identical
to `MSK12C02.pdf` and contains no drawing, verified by MD5. Its §8.1 refers the reader to an
"outside drawing page" that is not distributed with it. A screenshot is a fragile primary
source for the one part that has already been rejected once by a fab. Replace it when a
proper copy can be obtained.

---

## Passives: land patterns not changed

| Part | Datasheet | Package data | Action |
|---|---|---|---|
| CC0603KRX7R9BB104 (C1: C6) | `CC0603KRX7R9BB104-YAGEO-CC-series.pdf` | 0603: 1.6 ±0.15 × 0.8 ±0.15 × 0.8 ±0.15 | none: uses KiCad's IPC-7351 land |
| CL21A106KAYNNNE (C8) | `CL21A106KAYNNNE-Samsung-CL21A-series.pdf` | CL21A = 0805 (2012) | none: as above |
| CL21A226MAQNNNE (C9, C10) | same Samsung series document | CL21A = 0805 (2012) | none for the footprint: **see below** |
| 0603WAF series (R1: R14) | `UNI-ROYAL-0603WAF-series.pdf` | 0603 thick film | none: as above |

**C10, resolved 2026-08-07.** Schematic `Value` corrected from `100uF` to `22uF` to match
the MPN `CL21A226MAQNNNE` actually on the BOM. The rail carries C9 + C10 = 44 µF of bulk,
and the ME6211C33 LDO requires only 1 µF at its output, so 22 µF is electrically sound.
The BOM keeps its note to consider a 1206-size 100 µF next revision for extra WiFi-burst
headroom on coin-cell power.

---

## Remaining work: datasheets now held, changes not yet made

| Part | Manufacturer | LCSC | Refs | Outstanding |
|---|---|---|---|---|
| **LSM6DS3TR-C** | STMicroelectronics | C967633 | U2 | LGA-14, 0.5 mm pitch: the tightest land on the board. Courtyard 0.098 mm inside the pads on all four sides. No `F.Fab`. Dead 3D model path. |
| **CR2032-BS-6-1** | Q&J | C70377 | BT1 | Courtyard **2.240 mm** inside the pads. `(attr through_hole)` on an SMD holder. Footprint named "TH" while its own 3D model is named "SMD". Keep-out needed under the cell (74 % copper there today). |
| **TS-1187A-B-A-B** | XKB Connection | C318884 | SW1, SW2 | Courtyard 0.950 mm inside the pads. No pin-1 marker. Dead 3D model path. |
| **KT-0603R** | Hubei KENTO | C2286 | D1: D24 | ×24 placements. **Zero** courtyard clearance in y. Ø0.20 mm silk dot centred on pad 1's corner: ink on the land, on every one. Dead 3D model path. |
| CC0603KRX7R9BB104 | YAGEO | C14663 | C1: C6 | Uses KiCad's IPC-7351 land: low priority. Confirm dielectric/voltage. |
| CL21A106KAYNNNE | Samsung | C15850 | C8 | As above. |
| CL21A226MAQNNNE | Samsung | C45783 | C9, C10 | Resolved: schematic Value corrected to 22 µF, matching the MPN. |
| 0603WAF-series | UNI-ROYAL | C22962/25804/23162/25803 | R1: R14 | As above. |
| **C12** |: | *none* | C12 | No part chosen. 62 pF NP0, 56 to 68 pF window, tuned against the coil after VNA. The ST25DV datasheet sets the target; the part decision comes after that. |

---

## How to read a datasheet for this purpose

For each part, four things produce four changes:

1. **Mechanical data table** (dimensions D, E, E1, b, e) → the `F.Fab` body outline
2. **Recommended footprint / land pattern figure** → pad size, pitch, span
3. **Pin definitions table, "Type" column** → pin electrical types, which is what makes ERC work
4. **Any keep-out, thermal or layout note** → zones and placement constraints

If a datasheet gives no recommended land pattern, IPC-7351 is the fallback authority, and we do
not hold it. Record that as a gap rather than inventing a pattern.

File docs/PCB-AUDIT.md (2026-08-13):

# PCB audit: "6 Horribly Common PCB Design Mistakes"

Source: YouTube video `Z9nycymUd-I`, transcript pulled and checked point by
point against the board. Every finding below is measured from
`hardware/NeuralCard.kicad_pcb`, not assumed.

Verdict: clean on three of the six, real work on two, one does not apply.
**Two findings were fixed immediately and shipped as v2.3.1** (sharp corners,
U1 decoupling). The rest are backlog for whatever revision follows the first
prototype, each needs either a new component or disturbs verified copper,
so they are best decided once a physical board exists.

---

## 1. Incorrect traces: sharp angles FIXED

The video's rule: avoid interior angles below 90 degrees; acid traps and
field concentration at sharp corners. Measured on the board, five corners
with an interior angle under 89 degrees:

| Net | Location (mm) | Angle |
|---|---|---|
| +3V3 | 79.5, 8.8 | **0** (doubled-back segment) |
| CP6 | 43.5, 24.1 | 45 |
| CP5 | 67.8, 34.3 | 45 |
| NFC_ANT_B | 8.0, 14.2 | 45 |
| GND | 37.5, 33.8 | 83 |

**Resolved.** The 0-degree "corner" turned out to be a *duplicate track*,
two identical +3V3 segments stacked on the same path, a leftover from the
power-repair routing. Deleted. The other four were genuine acute vertices and
were chamfered (0.25-0.40 mm), converting each 45/83-degree vertex into two
obtuse ones. Re-scan reports **0 corners below 90 degrees**; DRC unchanged at
zero.

Note the NFC coil corner: the video exempts printed antennas from this rule,
but a 0.36 mm chamfer changes the loop area by ~0.05 mm2 out of ~60 mm2,
far below the C12 tuning tolerance, while still removing the acid trap.

Nothing else in this category: no high-current traces are undersized (the
charlieplex lines carry ~10 mA), and there are no analog signal traces
running parallel to fast digital ones.

## 2. Decoupling capacitors U1 FIXED, rest deferred

The video's rule: each power pin gets a pair, ~10 uF bulk for load
transients plus ~0.1 uF close in for high-frequency noise, and the small
one must sit right at the pin or its effect is largely lost.

Measured distance from each +3V3 cap to the nearest IC power pin:

| Cap | Value | Nearest power pin | Distance | Status |
|---|---|---|---|---|
| C5 | 100 nF | U2.8 (IMU) | **2.1 mm** | good |
| C9 | 22 uF | U3.5 (LDO out) | 3.5 mm | good (bulk) |
| C7 | 1 uF | U3.5 | 4.5 mm | good |
| C10 | 22 uF | U3.5 | 4.9 mm | good (bulk) |
| C1 | 100 nF | U2.12 | 6.2 mm | marginal |
| C11 | 100 nF | U4.8 (NFC) | 7.4 mm | marginal |
| C2 | 100 nF | U2.12 | 11.1 mm | too far |
| C3 | 100 nF | U2.8 | 23.1 mm | too far: rail cap, not decoupling |
| C8 | 10 uF | U1.2 | 21.8 mm | fine as battery-side bulk |

**U1, the ESP32, has no local decoupling at all**, nearest 100 nF is 11 mm
away. Mitigating fact: the WROOM-1 is a module with internal decoupling on
its 3V3 pin, which is why boards like this work in practice. Espressif still
specifies an external 0.1 uF + 10 uF adjacent to pin 2.

**Done, C2 relocated to U1's power pins.** C2 was a leaf component: its
+3V3 pad was a dead-end stub hanging off C1, and its ground ran 18 mm back to
U1 through a bridge added during the ground repairs. Moving it therefore cost
nothing that was carrying other traffic:

- C2 moved from (21.0, 21.5) to (20.5, 35.25), rotated 90 degrees, sitting
  directly beside U1 pins 1 and 2
- The redundant 16 mm ground bridge (6 segments, 4 vias) and the dead +3V3
  stub were deleted, the same connection is now made in 0.8 mm
- New legs: +3V3 1.35 mm to the via feeding pin 2, GND 0.80 mm to the pin-1
  stub. Loop area is now small enough to actually decouple.

**Distance to U1 pin 2: 11.1 mm -> 2.8 mm.** No schematic change was needed:
C2 is still the same 100 nF between +3V3 and GND, only its placement moved.
Verified after: DRC 0 violations, 0 unconnected, every net still a single
connected cluster (GND 42 pads, +3V3 23 pads).

**Still open** (each needs a new part or disturbs verified copper):

- 10 uF bulk companion beside C2 at U1, needs a new component in the schematic
- 1 uF companion beside C5 so the IMU has a true bulk+HF pair, new component
- Move C11 to within ~2 mm of U4 pin 8
- C3 (23 mm from anything) becomes a deliberate rail cap or moves, its ground
  pad is an endpoint of the battery-cluster bridge, so moving it means
  re-routing verified copper. Decide, then document.

## 3. Length equalisation of high-speed traces: not applicable

The rule targets parallel buses and clock trees where edge timing must be
preserved. This board has one differential pair, USB D+/D-, at **full speed
(12 Mbps)**. The pair is 100.1 mm and 75.9 mm, a 24 mm skew, about 130 ps,
against a 52 ns half-bit period. That is 0.25% of the bit time; irrelevant at
FS, and it would only start to matter at 480 Mbps High-Speed, which the
ESP32-S3's native USB does not do.

No action. Worth recording so a future reviewer does not "fix" it.

## 4. Antenna feed lines needs analysis, not assumption

Two radios here, and the video's rule applies differently to each:

**ESP32 2.4 GHz**, the module carries its own antenna and matching network.
Nothing to impedance-match on our board. What we owe it is the keepout, and
v2.2 already cleared all copper from the antenna zone. Verified clean.

**NFC 13.56 MHz coil**, this is where the board deviates from the video's
advice, and it needs deciding rather than defending:

- Coil traces are 0.2 mm, the same as signal routing. NFC coils normally use
  wider traces to lower resistance and raise Q.
- Ground pour is partially present under the coil region: sampled 71/140
  points on F.Cu and 44/140 on B.Cu. **Ground under an NFC coil couples to
  the field and lowers Q**, most ST25DV reference layouts specify a clear
  keepout under and around the antenna.

A future revision should either widen the coil and add a proper keepout beneath it, or
accept reduced read range as a documented trade. Measure the v2.3 prototype's
actual read range first, if a tap works reliably at 1-2 cm, this may be an
optimisation rather than a defect. Note C12's value (currently 68 pF
placeholder) must be re-tuned after any coil geometry change.

## 5. Component placement: mostly clean

- **Inductors**: none on the board, so no mutual-coupling concern
- **Heat**: no power resistors; the LDO handles at most ~150 mA, negligible
- **Switching regulator**: none, an LDO is used precisely because it is quiet
- **AC mains**: none, battery and USB only

The one placement item worth attention is the decoupling work in section 2,
which the video itself files under this heading.

## 6. Grounds and ground planes known limitation, by design

The video recommends 4 layers with dedicated power and ground planes, and
star-point returns on 2-layer boards.

This is a **2-layer board**, chosen so the artwork reads through and the cost
stays at $2/board. Consequences, honestly stated:

- Ground is a poured plane on both layers, heavily stitched, and after the
  v2.3 work every ground pad is on one connected plane (verified: single
  cluster, 42 pads). That is far better than daisy-chained returns.
- But the plane is perforated by the charlieplex routing, so return paths are
  not ideal, and the earlier corridor study measured that 94% of IMU_INT,
  88% of SDA and 82% of SCL run with no reference copper directly beneath.
- With a quiet LDO, no switcher, no mains, and slow signals, this is
  acceptable. It would not be acceptable on a board with fast edges.

**Option, not obligation:** going 4-layer would fix the reference-plane
gaps outright and cost roughly 3-4x per board. Worth it only if the
prototype shows I2C or USB reliability problems. Cheaper intermediate step:
add ground stitching vias flanking the USB pair and the I2C lines.

---

## Backlog for the next revision

1. ~~Local decoupling at U1 pin 2~~, **done in v2.3.1**, C2 relocated to
   2.8 mm. A 10 uF bulk companion still wants adding (new component).
2. ~~Fix the five sub-90-degree corners~~, **done in v2.3.1**, zero remain.
3. IMU bulk companion cap; pull C11 in to U4; resolve C3
4. NFC coil: widen traces + keepout under the coil, retune C12, pending
   read-range measurement on the v2.3 prototype
5. Optional: ground stitching along USB and I2C, or a 4-layer stack if the
   prototype misbehaves
6. Already carried over from earlier reviews: consider 1206/100 uF for C10

Nothing here blocks building v2.3.1. Every remaining item is an improvement
to make once the physical board has told us which of them actually matter.

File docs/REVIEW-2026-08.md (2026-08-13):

# NeuralCard: design review, August 2026

Reviewed at `main` (`6a64aac`), working tree clean. Board `hardware/NeuralCard.kicad_pcb`:
2 layers, 0.8 mm, 85.6 × 53.98 mm, 57 footprints, fully SMT, ESP32-S3-WROOM-1 + LSM6DS3TR-C
IMU + ST25DV04KC NFC tag + etched NFC coil + 24 charlieplexed LEDs + CR2032.

Tools: KiCad 10.0.3 (`kicad-cli`). Every measurement below was taken from the board file,
the project file, the libraries, or a tool run, not inferred. Nothing was changed.

**Verdict: blocked.** Four defects prevent the product working as designed. Several more
would fail a fab or assembly review. The board currently reports `Found 0 violations` because
the checks that would report them are switched off or set against a threshold of zero.

---

## Root cause: the design is not datasheet-driven

This is the finding that explains most of the others.

The repo holds **one datasheet, `hardware/datasheets/ESP32-S3-WROOM-1.pdf`, for thirteen
distinct footprints.** Eleven of the thirteen are unverified `easyeda2kicad` downloads, still
in KiCad-5 `(module …)` syntax with v6 fragments spliced in by hand. They have never been
round-tripped through the footprint editor, and their defects are consistent with
auto-generation rather than transcription from a mechanical drawing:

- **No `F.Fab` geometry on 11 of 13 footprints.** `F.Fab` *is* the datasheet body outline.
  Its absence is direct evidence nobody transcribed one.
- **Every courtyard wraps the body and ignores the pads**, an auto-generated shape, not a
  measured one.
- **Pin-1 "markers" are Ø0.12 mm origin artifacts** at 0.06 mm line width, below any silk
  minimum. They will not print.
- **`(attr through_hole)` on two all-SMD footprints**, nobody checked what the part is.

And the one datasheet that *is* held specifies the requirement the board's worst defect
violates: the ESP32-S3-WROOM-1 sheet shows a **"Keepout Zone"** in its pin layout (§3.1) and a
**7.49 mm "Antenna Area"** in the module dimensions. That zone is 84% copper on this board.

The one footprint on the board that passes every check, **SW3**, got there by referencing
KiCad's shipped `SW_SPDT_Shouhan_MSK12C02` unmodified. Not by transcribing a datasheet either,
but by trusting a library that already had.

---

## BLOCKER: the product does not work as designed

### B1. The ESP32 antenna keep-out is flooded with ground copper

Espressif's mandatory clearance zone, in board coordinates **x 23.0 to 41.0, y 37.36 to 43.39**
(the pad-free module end, marked by the footprint's own `B.SilkS` boundary lines), measures:

| Layer | Copper coverage |
|---|---|
| F.Cu | **84.4 %** |
| B.Cu | **81.3 %** |

There is no keep-out zone anywhere near it. The requirement is stated in the datasheet in this
repo. This alone prevents the WiFi working to spec, and it is not recoverable in firmware.

**Fix:** add a keep-out over the antenna area on *both* copper layers, Espressif's own
guidance is all-layer, and re-pour. Confirm against §3.1 and Figure 10.1 of the module
datasheet rather than against the silk outline.

### B2. Five ground islands are electrically isolated from the main plane

GND has **no tracks at all** on this board; the 28 GND vias are the only link between the
F.Cu and B.Cu pours. Five groups are stranded:

| Isolated region | Area | Pads stranded on it |
|---|---|---|
| F.Cu 4.47 to 27.53 × 4.83 to 10.47 + B.Cu 21.31 to 24.32 × 7.05 to 9.47 | 73.97 mm² | **U2.6, U2.7: the IMU's only ground pins** |
| B.Cu 21.39 to 26.63 × 4.66 to 18.06 | 22.40 mm² | C1.2, C5.2 |
| B.Cu 6.60 to 8.42 × 4.26 to 8.81 | 3.93 mm² | **U4.4: the ST25DV's only ground pin** |
| B.Cu 10.36 to 11.20 × 4.82 to 8.03 | 2.42 mm² | C11.2 |
| B.Cu 21.39 to 22.24 × 20.83 to 21.92 | 0.76 mm² | C2.2 |

The IMU and the NFC tag have no ground return. Four of the five 100 nF local decouplers have
their ground ends floating.

`kicad-cli pcb drc --severity-all` already reports these as **5 unconnected items**. Commit
`bf5ac61 "fix: pour islands cleared"` did not clear them. Island removal did not catch them
because each island touches a pad of the net, a clean island-removal result is not evidence
of zero floating copper.

**Fix:** stitch each region to the main plane, or reroute so the pour is continuous. Re-run
DRC and require zero unconnected items before release.

### B3. The ESP32 has no decoupling capacitor

U1 has a **single power pin** (pad 2, `+3V3`, at 23.250, 34.620). Measured distance to the
nearest same-net capacitor:

| Cap | Distance | Approx. trace inductance at Ott's 10 nH/in |
|---|---|---|
| C2 (100 nF) | **13.46 mm** | ~5.3 nH |
| C1 (100 nF) | 18.37 mm | ~7.2 nH |
| C8 (10 µF bulk) | **21.80 mm** | ~8.6 nH |

Nothing is placed against pad 2. For comparison, U2 (the IMU) has C5 at 2.10 mm, so the
practice exists on this board, it just was not applied to the part that needs it most: the
fastest, highest-current device and a 2.4 GHz transmitter.

Bulk capacitors C9/C10 sit 25.8 mm from where power actually enters at SW3.

**Fix:** a 100 nF as close to pad 2 as placement allows, on the same side, with its ground via
adjacent rather than at the end of a stub.

### B4. A CR2032 cannot run an ESP32-S3 with WiFi

Transmit peaks around 350 mA against a cell rated roughly 3 mA continuous and 15 mA pulse.
The 132 µF of bulk MLCC on the board does not bridge that, and it sits 26 mm from the switch.

This is a power-architecture problem, not a layout problem, and it sits upstream of everything
else in this document. Options are a different cell chemistry, a supercapacitor across the
rail, or accepting that the radio only runs on external power.

---

## HIGH: will cause a rejection, a wrong build, or a silent failure

### H1. DRC is checking against zero

`hardware/NeuralCard.kicad_pro`, `board.design_settings.rules`:

```
min_clearance: 0.0        min_track_width: 0.0     min_connection: 0.0
min_silk_clearance: 0.0   solder_mask_to_copper_clearance: 0.0
```

`clearance` and `track_width` are both at severity **error** and *cannot fire*, because the
constraint they check against is zero. No fab process window was ever entered into Board Setup.

This is more dangerous than a rule set to Ignore: an audit of severities reports it compliant.
The CHANGELOG's "DRC 0 clearance violations" is therefore not a result.

**Fix:** enter JLCPCB's published minimums for the ordered class into Board Setup → Constraints,
then re-run.

### H2. 29 of 57 placements reference a 3D model path that does not exist

Every `easyeda2kicad` footprint hard-codes an absolute path:

```
/absolute/path/to/project/JLC.3dshapes/LED0603_L1.6-W0.8-H0.6.wrl
```

That directory does not exist. Meanwhile `hardware/JLC.3dshapes/` holds matching `.step` **and**
`.wrl` files for all 11 parts, and `${KIPRJMOD}` is already used correctly in `fp-lib-table`.

Affected: 24 LEDs + 2 tact switches + BT1 + U1 + U2. Nothing in KiCad complains, a wrong or
missing 3D model produces no DRC error and no electrical consequence, which is why it survived.
It breaks any mechanical fit check, exploded diagram, or enclosure work downstream.

**Fix:** rewrite the model paths to `${KIPRJMOD}/JLC.3dshapes/…` and prefer the `.step` files
already present.

### H3. Silkscreen is printed onto exposed pads

The fab export (`hardware/tools/export_fab.py`) omits `--subtract-soldermask`. Re-exporting
with it changes both silk layers materially, F.Silkscreen 350,440 → 352,217 bytes, 112 diff
lines; B.Silkscreen 172,664 → 178,312, 280 diff lines. The flag adds clearance apertures that
clip silk off exposed copper.

Separately, `LED-SMD_L1.6-W0.8-R-RD.kicad_mod` places a Ø0.20 mm silk dot centred on pad 1's
corner, **on all 24 LEDs**:

```
(pad 1 smd rect (at 0.75 0.00) (size 0.800 0.800) …)      → x 0.35..1.15
(fp_circle (center 0.80 -0.40) (end 0.85 -0.40) (layer F.SilkS))
```

Marking ink is a non-wettable coating. Ink on a land is a joint that will not form.
`silk_over_copper` is set to `ignore`, so this has never been reported.

**Fix:** add `--subtract-soldermask` to the export, and move or delete the pin-1 dot in the
LED footprint.

### H4. ERC electrical checking is disarmed board-wide

Pin electrical types across the project libraries:

| Library | `unspecified` | other |
|---|---|---|
| `JLC.kicad_sym` | 85 of 95 | 6 bidirectional, 4 input |
| `ST25DV.kicad_sym` | 8 of 8 |: |

Zero `power_in`, zero `output`, zero `passive`. KiCad treats `unspecified` as compatible with
everything, so ERC on the ESP32's supply pins, the LDO output and the ST25DV's I²C lines is not
weak, it is off. A power output shorted to a power output would not fire.

The 41 `pin_to_pin` warnings currently reported all trace to this one cause.

**Fix:** type the pins on the parts that matter, supplies as `power_in`, regulator outputs as
`power_out`, I²C as `bidirectional`. This is what makes ERC mean anything.

### H5. C12 has no part number: the same failure that sent SW3 back from the fab

`fab/BOM_JLCPCB.csv`, line 51:

```
"62pF NP0 0603 (tune after VNA; 56-68pF window)",C12,C0603,select-at-order
```

The CHANGELOG describes SW3's root cause in these words: *"The BOM had the part as
'select-at-order' with a note to verify the footprint against whatever got chosen; that
verification never happened."*

The same string is in the same file today, on the NFC tuning capacitor, a value-critical part
where matching by value and package alone is exactly the wrong-part risk.

Also open: **C10's schematic `Value` is `100uF`, while its LCSC number and MPN are a 22 µF
part** (`C45783`, `CL21A226MAQNNNE`). The hand-written BOM papers over the discrepancy with a
parenthetical rather than resolving it.

**Fix:** resolve C12 before the next order. Reconcile C10's value against its part number.

### H6. Return paths are largely unreferenced

For each net, the fraction of track length with no ground copper on the opposite layer beneath it:

| Net | Length | Unreferenced |
|---|---|---|
| IMU_INT | 34.89 mm | **94.1 %** |
| SDA | 97.77 mm | 88.1 % |
| SCL | 94.82 mm | 82.2 % |
| CP4 | 136.85 mm | 75.3 % |
| +3V3 | 253.20 mm | 43.0 % |

Cause: a continuous copper-free band at roughly **y 3.4 to 5.0, x 15 to 80 on both layers**, a
~60 mm slot cut by the signal bundle feeding the LED resistor row. The top 2.5 mm edge strip of
plane is nearly detached from the body. The B.Cu plane around J1's six pads merges into a
second continuous void at x 67 to 79, y 48.6 to 51.

Return current forced around a discontinuity of this length raises loop area, ground
inductance, radiation and crosstalk together.

### H7. Every ground pad is welded solid to the plane, while the project file claims otherwise

Both zones use `(connect_pads yes (clearance 0.3))`, KiCad's **solid** mode. The
`(thermal_gap 0.5) (thermal_bridge_width 0.5)` tokens beside it are inert. Confirmed
geometrically by rasterising the fill around BT1 pad 2, C1 pad 2 and U1's thermal-pad array:
continuous copper across every pad, no annular gap, no spokes.

Meanwhile `.kicad_pro` sets `min_resolved_spokes: 2` and `starved_thermal: error`, **rules
that can never fire, because there are no spokes.** The project file reads as if thermal relief
is being policed.

For a fab-assembled all-SMD board, solid connection is defensible and arguably correct for
decoupling capacitors. The defect is the mismatch: settings that describe a policy the board
does not implement.

### H8. Exposed plane copper under the coin cell

The region under BT1 (x 52 to 72, y 18 to 38) measures **74.0 % copper on B.Cu**, the cell's own
side, and 77.8 % on F.Cu. Solder mask is the only barrier between a shifting cell and the
ground plane.

**Fix:** keep-out under the cell body on the cell's side.

---

## MEDIUM: quality, manufacturability, and process

| # | Finding |
|---|---|
| M1 | **Courtyards enclose the body and ignore the pads** on every project footprint. Worst: `SO-8` (U4) 1.684 mm of pad outside; `BAT-TH_CR2032` 2.240 mm; `SW-SMD_4P` 0.950 mm. The 24 LEDs have *zero* clearance in y. |
| M2 | **`ProgPads_1x6` (J1) has no courtyard at all**: this is what `missing_courtyard: ignore` is hiding. |
| M3 | **`(attr through_hole)` on two all-SMD footprints**: `BAT-TH_CR2032-BS-6-1` and `SO-8_…` (U4). Drives position-file generation and PCBA classification. Same failure class as the SW3 rejection, still live. `footprint_type_mismatch` is set to `ignore`. |
| M4 | **Merged drill file.** `NeuralCard.drl` is one file, 87 hits. `--excellon-separate-th` splits it into PTH (85) and NPTH (2). Many fabs expect the split. |
| M5 | **BOM is missing four required columns**: `Quantity`, `MFR`, `MFR_PN`, `Basic/Extended`. The schematic already carries `Manufacturer` and `MPN` on all 54 symbols; the hand-maintained BOM discards them. `kicad-cli sch export bom --fields …` produces a correct grouped BOM directly. |
| M6 | **BOM `Footprint` column disagrees with the board on 21 of 52 rows** (`R0603` vs `R_0603_1608Metric`). Benign as naming: but this is the channel through which SW3's improvised land shipped. |
| M7 | **FID1 to 3 raise `extra_footprint`.** They carry `exclude_from_bom exclude_from_pos_files` but not `board_only`. Fix at the footprint, not by downgrading the rule. |
| M8 | **Three revisions, three answers.** `.kicad_pcb` has no `title_block` at all; schematic says `V0.1`; silkscreen says `v2.2.2`. Only the silk is right. |
| M9 | **Seven keep-out zones, none named.** Zone 4 (x 3.6 to 82.4, y 49.9 to 50.7, tracks/vias forbidden, copper allowed) has no recorded purpose. |
| M10 | **Stitching is sparse and the periphery is essentially unstitched.** 28 GND vias; nearest-neighbour spacing 2.77 to 16.66 mm; distance from any point to the nearest via has a median of 6.1 mm and a **maximum of 23.4 mm**; 46 % of board area is more than 6.5 mm from a stitch. Edges: 2 vias left, 3 right, **1 top**, 3 bottom. |
| M11 | **One net class for everything.** `Default`, 0.2 mm track / 0.6 mm via, covers the battery rail, the NFC antenna and 24 LED drives alike. |
| M12 | **The NFC coil keep-out leaks.** Drawn to the courtyard at y 15.4 while the outer turn tops out at y 16.75. Fill survives 1.35 mm from the coil: the strip x 2.4 to 14.6, y 13.4 to 15.5 measures 79.4 % copper on F.Cu and 49.6 % on B.Cu. |
| M13 | **SW3's four shield tabs and two mechanical pads carry no net**: netless metal on the user-facing power switch. `ANT1` pad 3 (1.2 mm plated hole) is likewise netless. |
| M14 | **Unplaced library footprints carry live defects.** `USB-C_SMD-TYPE-C-31-M-12_1` has plated holes with **size 0.75 over drill 0.75: zero annular ring**, a guaranteed fab reject if ever used. `SOT-23-5` and `SOT-23-6` have courtyards rotated 90° relative to their pads. |
| M15 | **Dead library entries.** `NeuralCard_Custom.kicad_sym` is 102 bytes with zero symbols and is registered in `sym-lib-table`. Five of ten `JLC.pretty` footprints are unplaced. |
| M16 | **`ProgPads_1x6` pad labels are 0.70 mm** against the project's own `min_text_height: 0.8`; `text_height` is set to `ignore`. |
| M17 | **`--schematic-parity` is off by default in `kicad-cli`.** With it: 108 `footprint_symbol_mismatch`, 54 `footprint_symbol_field_mismatch`, 3 `extra_footprint`. The 108 are systemic: board `Value` fields hold designators while schematic `Value` fields hold footprint names, and board FPIDs lack library prefixes. **Do not run "Update PCB from Schematic" before fixing this**; it would rewrite the value and footprint of nearly every part. |

---

## What is right, and should not be disturbed

- **SW3 is correct.** Pad-for-pad identical to KiCad's shipped `SW_SPDT_Shouhan_MSK12C02`,
  verified by diffing every `at`, `size` and `drill`. NPTH locators correct, LCSC `C431540`
  matches, 3D model resolves. It is the only footprint on the board that passes every check.
- **The gerbers match the board.** Re-plotted F.Cu, B.Cu, both silks and Edge.Cuts and compared
  by checksum ignoring comment records, identical. The 20-minute mtime gap is a checkout
  artifact, not drift.
- **No stray `.gbr` contamination** in the current `fab/`. `hardware/fab.old-jul22/` is the
  contaminated ancestor, it ships 10 forbidden documentation layers, and the current bundle
  is the fix.
- **The CPL is correct.** Header already renamed, 52 rows, mm, exact designator match with the
  BOM in both directions. `ANT1`, `J1` and `FID1 to 3` are correctly excluded.
- **Decoupling values are consistent**, 100 nF locals throughout, no mixed-decade ladder, so no
  parallel antiresonance. Bulk (132 µF) comfortably exceeds the sum of the locals, no aluminium
  electrolytic.
- **Fill type is solid** on both zones, which is current practice.
- **The front-face silkscreen artwork is deliberate.** 398 of the 414 suppressed violations are
  the neural-network illustration, and the front face carries no designators by design. The nine
  `ignore` keys were a considered decision by someone who looked, not negligence. They should
  be *scoped*, not lifted wholesale.

---

## Suggested order of work

1. **B1** antenna keep-out, cheapest fix, largest consequence, and the requirement is in the
   datasheet already in the repo.
2. **B2** ground islands, already reported by DRC; five stitches.
3. **B3** ESP32 decoupling, one part, one via.
4. **H1** enter real fab constraints, so DRC starts checking something.
5. **H5** resolve C12 and C10 before any order.
6. **H2** 3D model paths, one search-and-replace.
7. **H3** add `--subtract-soldermask`; fix the LED silk dot.
8. **H4** type the pins that matter.
9. **B4** power architecture, the largest question, and the one that may change the product.

Items M1, M3 are best fixed by re-drawing the affected footprints from manufacturer datasheets
rather than patching the `easyeda2kicad` output. That is the same work as fixing the root cause.

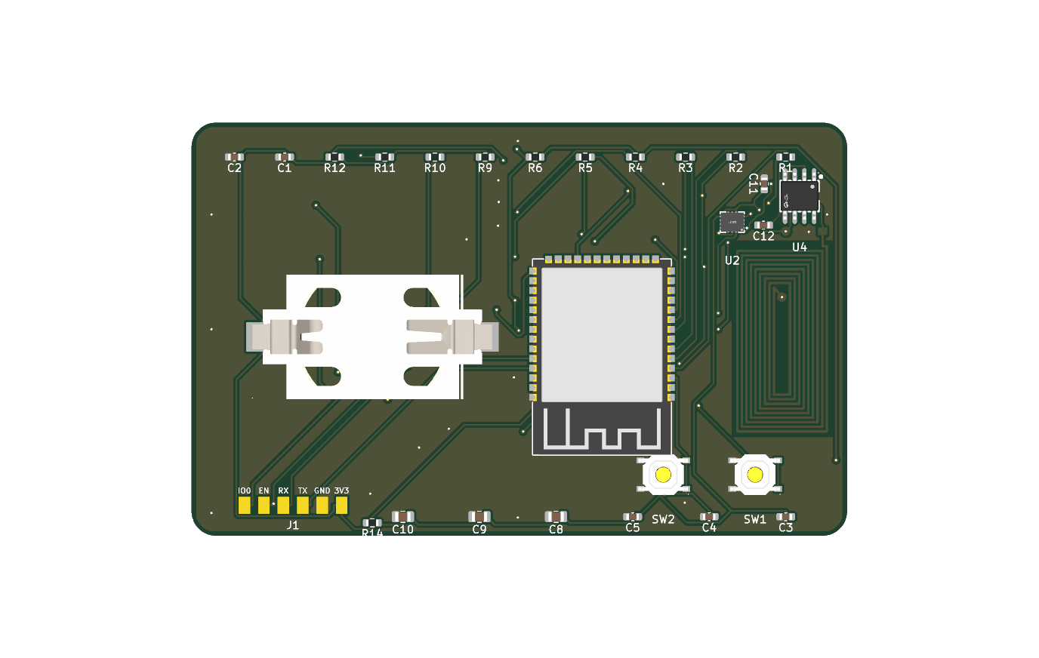
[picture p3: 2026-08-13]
render/NeuralCard_back_nfc.png

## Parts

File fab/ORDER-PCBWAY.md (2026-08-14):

# What to send PCBWay

Everything in this folder is generated from the board as it stands, not from an
earlier revision. Regenerate it if the board changes again.

## Files to upload

| File | What it is |
|---|---|
| `NeuralCard_gerbers.zip` | 9 Gerber X2 layers, the drill file, the drill map and the job file |
| `BOM_PCBWay.csv` | 21 lines, 61 placements, manufacturer part numbers with approved alternates |
| `NeuralCard-cpl.csv` | 61 placements, Designator / Mid X / Mid Y / Layer / Rotation |

The loose Gerbers sit alongside the zip for inspection. Upload the zip.

## Board specification

| Setting | Value |
|---|---|
| Size | 85.6 by 54 mm (ID-1, standard business card) |
| Layers | 2 |
| Thickness | 1.6 mm |
| Copper | 1 oz |
| Soldermask | green |
| Silkscreen | white |
| Surface finish | HASL, or ENIG if the budget allows |
| Min track and clearance | 0.15 mm used, 0.1 mm capability assumed |
| Min drill | 0.3 mm |
| Castellation, edge plating | none |

ENIG is worth asking about. It costs more and changes nothing in the Gerbers, but
this board is meant to be handed to people and gold pads look considerably better
than tinned ones on a card. 0.8 mm thickness is the other upgrade worth pricing:
it makes the board feel like a card rather than a circuit board.

## Assembly

Both sides are populated. 24 red LEDs on the front, 37 parts on the back.

| Item | Detail |
|---|---|
| Placements | 61 total, 24 top and 37 bottom |
| Unique parts | 21 |
| Through hole | BT1 coin cell holder, plus the mixed SMD and through hole legs on J2 and SW3 |
| Stencil | yes, needed for the 0.5 mm pitch LGA-14 at U2 |
| Fiducials | three on the bottom, at top-left, bottom-left and bottom-right |

The CR2032 cell itself is not on the BOM. Holders ship empty.

There are no fiducials on the top side. If the placement machine wants them for
the LED pass, say so and three 1 mm pads can be added in clear corner space
without touching any routing.

## Two lines to confirm before the order is built

U3 is an ME6211C33M5G-N. No Western distributor carries it, so it has to come
from local stock. If that is a problem, the approved substitute is
AP2112K-3.3TRG1 from Diodes, which has the identical SOT-23-5 pinout and needs no
board change.

U4 is an ST25DV04KC-IE6S3, which is the active part. The older ST25DV04K-IER6S3
is marked not recommended for new designs but is still deeply stocked, and it is
listed as the fallback. Either builds.

Both are called out in the BOM's Remarks column, along with the parts that must
not be substituted at all.

## Verification behind this package

DRC 0 violations and 0 unconnected. ERC 0 violations. Every pin in the schematic
compared against every pad on the board: 211 pads carrying nets, zero net name
disagreements, zero pins without a pad. BOM and placement file cross checked
against each other: 61 designators each, no part in one and missing from the
other.

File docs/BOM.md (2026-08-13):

# NeuralCard: Bill of Materials

**Project:** NeuralCard, AI business card (air-writing digit recognition)
**Owner:** Barakaeli Lawuo
**Assembly:** SMT. **All parts SMD/SMT except the CR2032 coin** (the holder BT1 is SMT; only the coin itself is non-soldered).
**Upload file:** `BOM_PCBWay.csv` for this build (manufacturer part numbers, approved
alternates, substitution rules). `BOM_JLCPCB.csv` is the upstream LCSC-keyed file.
Both pair with `NeuralCard-cpl.csv` for placements. See [`SOURCING.md`](./SOURCING.md).

> **Confirm every LCSC part number at the links below before ordering.** Actives/connectors
> were pulled directly from LCSC (footprints are catalogue-exact, in `Parts.pretty`).
> Passive (R/C) codes are common commodity parts, verify value/voltage/package on the
> linked page.

---

## 1. Active parts, connectors, electromechanical (confirmed JLC-exact footprints)

| Ref | Part | Value / role | Pkg | Qty | LCSC | Confirm link | Datasheet |
|---|---|---|---|---|---|---|---|
| U1 | ESP32-S3-WROOM-1-**N8R2** | MCU (radio unused) | module SMD | 1 | **C2913204** | [LCSC](https://www.lcsc.com/product-detail/C2913204.html) · [JLC](https://jlcpcb.com/partdetail/C2913204) | [Espressif PDF](https://www.espressif.com/sites/default/files/documentation/esp32-s3-wroom-1_wroom-1u_datasheet_en.pdf) (local ✓) |
| U2 | LSM6DS3TR-C | 6-axis IMU (air-writing) | LGA-14 | 1 | **C967633** | [LCSC](https://www.lcsc.com/product-detail/C967633.html) · [JLC](https://jlcpcb.com/partdetail/C967633) | [ST PDF](https://www.st.com/resource/en/datasheet/lsm6ds3tr-c.pdf) (open in browser) |
| U3 | ME6211C33M5G | 3.3 V LDO (USB→3V3) | SOT-23-5 | 1 | **C82942** | [LCSC](https://www.lcsc.com/product-detail/C82942.html) · [JLC](https://jlcpcb.com/partdetail/C82942) | [LCSC](https://www.lcsc.com/product-detail/C82942.html) |
| Q1 | AO3401A | P-MOSFET (coin auto-select) | SOT-23 | 1 | **C15127** | [LCSC](https://www.lcsc.com/product-detail/C15127.html) · [JLC](https://jlcpcb.com/partdetail/C15127) | [LCSC](https://www.lcsc.com/product-detail/C15127.html) |
| J1 | TYPE-C-31-M-12 | USB-C 16P (program + power) | SMD | 1 | **C165948** | [LCSC](https://www.lcsc.com/product-detail/C165948.html) · [JLC](https://jlcpcb.com/partdetail/C165948) | [LCSC](https://www.lcsc.com/product-detail/C165948.html) |
| D0 | USBLC6-2SC6 | USB ESD protection | SOT-23-6 | 1 | **C7519** | [LCSC](https://www.lcsc.com/product-detail/C7519.html) · [JLC](https://jlcpcb.com/partdetail/C7519) | [ST PDF](https://www.st.com/resource/en/datasheet/usblc6-2.pdf) (local ✓) |
| D1: D24 | KT-0603R (red) | Neuron LEDs (24×) | 0603 | 24 | **C2286** | [LCSC](https://www.lcsc.com/product-detail/C2286.html) · [JLC](https://jlcpcb.com/partdetail/C2286) | [LCSC](https://www.lcsc.com/product-detail/C2286.html) |
| BT1 | CR2032-BS-6-1 (Q&J) | Coin cell holder | SMD holder | 1 | **C70377** | [LCSC](https://www.lcsc.com/product-detail/C70377.html) · [JLC](https://jlcpcb.com/partdetail/C70377) | [LCSC](https://www.lcsc.com/product-detail/C70377.html) |
| SW1, SW2 | TS-1187A-B-A-B | Tact switch (BOOT, RESET) | SMD | 2 | **C318884** | [LCSC](https://www.lcsc.com/product-detail/C318884.html) · [JLC](https://jlcpcb.com/partdetail/C318884) | [LCSC](https://www.lcsc.com/product-detail/C318884.html) |
| SW3 | SHOU HAN MSK12C02 | SPDT slide switch: **power on/off**, in series with coin + terminal | SMD 8×2.8 mm, right-angle | 1 | **C431540** | [LCSC](https://www.lcsc.com/product-detail/C431540.html) · [JLC](https://jlcpcb.com/partdetail/C431540) | [LCSC PDF](https://www.lcsc.com/datasheet/lcsc_datasheet_2304140030_SHOU-HAN-MSK12C02_C431540.pdf) |

## 2. Passives: JLC **Basic** parts (verify value/voltage at link)

| Ref | Value | Pkg | Qty | LCSC (verify) | Confirm link | Role |
|---|---|---|---|---|---|---|
| R1: R6 | 220 Ω 1% | 0603 | 6 | C22962 | [LCSC](https://www.lcsc.com/product-detail/C22962.html) | LED charlieplex current limit |
| R7, R8 | 5.1 kΩ 1% | 0603 | 2 | C23186 | [LCSC](https://www.lcsc.com/product-detail/C23186.html) | USB-C CC1/CC2 sink |
| R9, R10 | 10 kΩ 1% | 0603 | 2 | C25804 | [LCSC](https://www.lcsc.com/product-detail/C25804.html) | EN + IO0 pull-ups |
| R11, R12 | 4.7 kΩ 1% | 0603 | 2 | C23162 | [LCSC](https://www.lcsc.com/product-detail/C23162.html) | I²C SDA/SCL pull-ups |
| R13 | 100 kΩ 1% | 0603 | 1 | C25803 | [LCSC](https://www.lcsc.com/product-detail/C25803.html) | P-FET gate bleeder (VBUS→GND) |
| C1: C5 | 100 nF X7R 50V | 0603 | 5 | C14663 | [LCSC](https://www.lcsc.com/product-detail/C14663.html) | Decoupling (ESP32 ×3, IMU, LDO) |
| C6, C7 | 1 µF X7R 25V | 0603 | 2 | C15849 | [LCSC](https://www.lcsc.com/product-detail/C15849.html) | LDO in/out |
| C8 | 10 µF 25V | 0805 | 1 | C5674 | [LCSC](https://www.lcsc.com/product-detail/C5674.html) | ESP32 bulk |
| C9 | 22 µF 16V | 0805 | 1 | C45783 | [LCSC](https://www.lcsc.com/product-detail/C45783.html) | Rail bulk |
| C10 | 100 µF 6.3V | 0805 | 1 | C15850 | [LCSC](https://www.lcsc.com/product-detail/C15850.html) | Ride-out cap (coin peaks) |

**Total placements: 52** per the current `fab/NeuralCard-cpl.csv`, 24 LEDs + 11 R + 10 C +
3 switches (SW1/SW2/SW3) + 3 ICs/module (U1/U2/U4) + BT1.

> **Sections 1 to 2 above are stale.** They still list the v2-removed USB-C power path
> (J1, D0, U3, Q1, R7, R8, R13, C6, C7), those nine parts are **not** in the current CPL.
> See `DESIGN.md` §0 for the removal and [`CHANGELOG.md`](../CHANGELOG.md) "Known issues".

---

## 3. Important ordering notes

1. **LSM6DS3TR-C (U2) is JLC "Standard PCBA only" + needs an assembly fixture.** Because of this
   one part, the whole board must use **JLCPCB Standard Assembly** (not Economic). Budget the
   one-time fixture fee. Confirm on the [JLC part page](https://jlcpcb.com/partdetail/C967633).
2. **LEDs are red (C2286), and must stay red.** Blue LEDs need ~2.8 to 3.2 V forward, which a
   3.0 V coin cannot drive with any margin, this was resolved in v2 by moving to red
   `KT-0603R` (Vf ~1.8 V). Do **not** revert to the old blue `C72041`: it contradicts
   `BOM_JLCPCB.csv` and the board's red footprint, and a 2026-08-02 LCSC check found
   **only 14 units in stock**, which cannot supply 24 per board.
3. **Power source selection (Q1 P-FET):** USB→LDO powers the rail and auto-disconnects the coin
   (no back-charge of the non-rechargeable CR2032, no diode drop). 100 % SMD.
4. **CR2032 holder height** adds ~3.5 mm on one side, normal for coin-cell cards.
5. **SW3 must be ordered as C431540 specifically.** It was previously "select-at-order" against
   an improvised land, which JLCPCB rejected at DFM on order SMT026072863054. The board now
   carries the datasheet-exact MSK12C02 footprint including 4 shield tabs and 2× 0.85 mm NPTH
   locating holes, a different slide switch will not seat. See [`CHANGELOG.md`](../CHANGELOG.md).
6. Passive LCSC codes are common JLC Basic parts, **verify each value/voltage** at its link.

---

## 3b. LCSC verification (2026-08-02)

All 14 LCSC codes in `BOM_JLCPCB.csv` resolved against the LCSC/jlcsearch API. Every code
maps to a real, well-stocked part, no substitutions or discontinuations found.

| LCSC | Qty | Resolved MPN | Stock | Unit $ |
|---|---|---|---|---|
| C2286 | 24 | KT-0603R | 7,824,832 | 0.0053 |
| C22962 | 6 | 0603WAF2200T5E | 3,413,507 | 0.0010 |
| C14663 | 6 | CC0603KRX7R9BB104 | 81,299,425 | 0.0022 |
| C318884 | 2 | TS-1187A-B-A-B | 918,009 | 0.0177 |
| C25804 | 2 | 0603WAF1002T5E | 37,165,617 | 0.0008 |
| C23162 | 2 | 0603WAF4701T5E | 9,126,951 | 0.0010 |
| C45783 | 2 | CL21A226MAQNNNE | 5,389,915 | 0.0197 |
| C2913204 | 1 | ESP32-S3-WROOM-1-**N8R2** | 17,776 | 5.0143 |
| C967633 | 1 | LSM6DS3TR-C | 47,071 | 0.9286 |
| C70377 | 1 | CR2032-BS-6-1 | 32,111 | 0.1621 |
| C15850 | 1 | CL21A106KAYNNNE | 12,668,317 | 0.0091 |
| C3304276 | 1 | ST25DV04KC-IE6S3 | 18,587 | 0.5271 |
| C25803 | 1 | 0603WAF1003T5E | 14,797,688 | 0.0009 |
| **C431540** | 1 | **MSK12C02** | 98,963 | 0.0471 |

**Parts cost ≈ $6.91/board**, 73% of it the ESP32 module.

Notes:
- **SW3 confirmed.** C431540 resolves to MSK12C02 with ~99k in stock, the DFM fix is sound.
- **U1 is N8R2, not N16R8.** Confirmed by the API; harmless here (PSRAM pins NC, int8 MLP
  fits 8 MB flash). Table above corrected.
- **51 of 52 placements carry a code.** The exception is **C12**, the NFC tuning cap,
  deliberately select-at-order pending VNA trim within the 56 to 68 pF window.

## 4. Datasheets (local copies in `datasheets/`)

| Part | Local file | Source link |
|---|---|---|
| ESP32-S3-WROOM-1 | `datasheets/ESP32-S3-WROOM-1.pdf` ✓ | [Espressif](https://www.espressif.com/sites/default/files/documentation/esp32-s3-wroom-1_wroom-1u_datasheet_en.pdf) |
| LSM6DS3TR-C | not downloaded (ST/LCSC block bots) | [ST datasheet](https://www.st.com/resource/en/datasheet/lsm6ds3tr-c.pdf): open in browser, save to `datasheets/` |
| ME6211C33M5G |: | [LCSC C82942](https://www.lcsc.com/product-detail/C82942.html) |
| AO3401A |: | [LCSC C15127](https://www.lcsc.com/product-detail/C15127.html) |
| USBLC6-2 | (download to datasheets/) | [ST](https://www.st.com/resource/en/datasheet/usblc6-2.pdf) |

---

## 5. NFC (v2.1 addition)

| Ref | Part | Package | LCSC | Notes |
|---|---|---|---|---|
| U4 | ST25DV04KC-IE6S3 dynamic NFC tag | SO-8 | [C3304276](https://jlcpcb.com/partdetail/STMicroelectronics-ST25DV04KCIE6S3/C3304276) | Extended, Economic PCBA OK |
| C11 | 100nF 0603 | 0603 | C14663 | VCC decoupling |
| C12 | 62pF NP0/C0G 0603 | 0603 | select at order | antenna tuning: verify with VNA; 56 to 68pF window |
| R14 | 100k 0603 | 0603 | C25803 | GPO open-drain pull-up |
| ANT1 | PCB coil 12x24.5mm, 9 turns 0.3/0.3 |: | (bare copper) | net-tie footprint, excluded from BOM/CPL |

Datasheet: [ST25DV04KC](https://www.st.com/resource/en/datasheet/st25dv04kc.pdf), open in
browser, save to `datasheets/` (ST blocks scripted downloads).

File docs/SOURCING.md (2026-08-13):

# Component sourcing for the PCBWay assembly run

This fork is prepared for assembly by PCBWay under their maker sponsorship
program. The upstream BOM was written against JLCPCB's in-house parts library, so
every line carried an LCSC part code and nothing else. PCBWay does not buy from
that library, so this file records where PCBWay actually gets parts and confirms
that every component on the board is reachable through one of those channels.

The order-ready file is [`fab/BOM_PCBWay.csv`](../fab/BOM_PCBWay.csv). The original
`fab/BOM_JLCPCB.csv` is kept unchanged so the two can be diffed.

## Where PCBWay buys components

PCBWay is not a parts trader. They procure per project, only against an assembly
order, through two channels.

The first is authorized Western distributors: Digi-Key, Mouser, Farnell element14,
Arrow, and Avnet. Anything with a real manufacturer part number and global stock
comes from here. Budget 5 to 7 business days for procurement, stretching to 7 to
10 if customs is slow.

The second is local Shenzhen distributors. This is their stated first preference,
because local stock is immediate and skips the import leg. This channel covers the
China market parts (HRO connectors, XKB switches, Uniroyal passives, KENTO LEDs)
that never appear in a Digi-Key search. LCSC part codes are still a usable pointer
here even though PCBWay is not LCSC, because these are the same commodity parts
moving through the same Huaqiangbei supply chain.

Four arrangements are on offer: PCBWay buys everything, PCBWay buys from suppliers
you name, you consign all parts, or a mix. Turnkey is the right choice for this
board. The BOM is small and entirely commodity, and consigning parts would add
shipping and customs on our side for no saving.

Their substitution policy is the one that shapes the BOM: no substitutes without
your approval. Anything ambiguous becomes an email round trip and a delay, so the
BOM pre-approves alternates wherever a swap is safe and forbids it where it is not.

## Where the sourcing data lives

Every placed part in `NeuralCard.kicad_sch` and `NeuralCard.kicad_pcb` now carries
three hidden fields next to the existing MPN, Manufacturer, and LCSC fields:

| Field | Holds |
|---|---|
| `Alt MPN` | approved drop-in replacement, or empty where none exists |
| `Alt Mfr` | manufacturer of that alternate |
| `Sourcing` | which channel to buy from, plus the substitution rule |

The decision travels with the design instead of living only in a spreadsheet, so a
future export cannot lose it. Both files pass DRC (0 violations, 0 unconnected) and
ERC (0 violations) after the change, which is expected since the fields are hidden
text on the fab layer and touch no copper.

## Parts that need a decision before ordering

21 unique parts, 61 placements. Three need an answer from PCBWay first.

### U3, the 3.3V regulator

The fitted part is an ME6211C33M5G-N from Nanjing Micro One. It is stocked at LCSC
and throughout the Shenzhen market, but Digi-Key and Mouser do not carry it at all.

If PCBWay quotes it from local stock, take it. If they push back or want to buy
Western, the approved substitute is an AP2112K-3.3TRG1 from Diodes Incorporated. It
has the identical SOT-23-5 pinout (1 VIN, 2 GND, 3 EN, 4 NC, 5 VOUT) and is rated
600 mA against the ME6211's 500 mA. Neither choice changes the board.

### U4, the NFC tag

The schematic fits an ST25DV04KC-IE6S3, which is the active part. The older
ST25DV04K-IER6S3 is marked not recommended for new designs by ST but is still
deeply stocked (Mouser showed over 38,000 units). Both are SO-8 with the same
pinout, so either will build.

Worth knowing: `fab/BOM_JLCPCB.csv` had drifted to the older ST25DV04K while the
schematic still specified the KC, because the K was substituted in at order time
when the KC ran low at LCSC specifically. That constraint does not apply to
PCBWay's channels. `BOM_PCBWay.csv` follows the schematic and asks for the KC, with
the K listed as the fallback.

### D1 to D24, the LEDs

All 24 must come from one part number and one brightness bin. The board displays
neural network activations as relative LED brightness, so a mixed bin reel makes
the output physically wrong rather than merely uneven. This is the one line where a
well meant substitution would quietly break the project, and it is called out in
the BOM remarks and the `Sourcing` field for that reason.

## Parts sourced locally, no concerns

J2 (USB-C receptacle), SW1 and SW2 (tactile switches), SW3 (slide switch), and BT1
(coin cell holder) are standard China market parts with deep local stock.

For three of them the footprint is specific to that exact body, so a substitute
needs a land pattern review first. The land patterns were measured out of the
footprint files rather than read off a datasheet:

| Ref | Land pattern | Substitution |
|---|---|---|
| BT1 | two 3.0 by 4.2 mm pads at +/-14.5 mm, 29 mm centres | check any candidate against this |
| SW1, SW2 | four pads 1.0 by 0.75 mm at (+/-3.0, +/-1.85) mm, 5.1 mm body, 1.5 mm high | any 4 pad SMD tact of this pitch fits |
| SW3 | 4 shield tabs plus 2 NPTH locating holes of 0.85 mm | none, a different switch will not seat |

J2 is the exception with a verified alternate. An XKB U262-161N-4BVC11 is
mechanically drop-in for the fitted TYPE-C-31-M-12: NPTH pegs at +/-2.89 against
+/-2.90 mm, shield legs at +/-4.32 against +/-4.33 mm, the same 4.18 mm shield row
spacing, and identical 0.5 mm signal pad X positions. The two land patterns differ
only in how long the signal pads are drawn, which is a library convention and not a
fit constraint.

The CR2032 cell itself is not on the BOM. Holders ship empty, so buy cells separately.

## Parts with global stock, no concerns

U1 (ESP32-S3-WROOM-1-N8R2), U2 (LSM6DS3TR-C), U5 (USBLC6-2SC6), and Q1 (AO3401A)
are carried by Digi-Key, Mouser, and LCSC alike.

Two cautions on U1. Never accept an ESP32-S3-WROOM-1U, because the U suffix is the
IPEX external antenna variant and this board's antenna keepout is cut for the PCB
antenna module. The memory variant is flexible: N8R2 is the fitted part and N16R8
is an acceptable upgrade if it is better stocked or similarly priced.

U2 is a 0.5 mm pitch LGA-14 with no exposed leads. It is the one part that genuinely
needs a stencil and a real reflow profile, which is a good argument for letting
PCBWay assemble the board rather than hand soldering it. It also cannot be
substituted at all, because the firmware binds its WHO_AM_I value and register map.

Q1 has an approved alternate in the DMG2301L from Diodes Incorporated. Any -30V P
channel MOSFET in SOT-23 with a gate threshold below 1.5 V will do, since it only
has to pass gate at 3.3 V logic.

## Passives

The 0603 and 0805 resistors and capacitors are commodity, and PCBWay house stock is
fine for all of them. The BOM lists a representative MPN plus an "any equivalent"
alternate so procurement never blocks on an exact brand.

Two exceptions. C12 must be C0G/NP0 dielectric and not X7R, because it tunes the
NFC antenna and an X7R part's voltage and temperature coefficients would detune the
resonance. The target is 62 pF with a workable 56 to 68 pF window, and the value may
be retrimmed after measuring an assembled board with a VNA.

R7 and R8 are the USB-C CC1 and CC2 pulldowns. 5.1k is fixed by the USB-C
specification and is what identifies this board as a sink. A close enough 5.6k can
stop some chargers enumerating it.

## What to send PCBWay

1. Gerbers and drill from `fab/`. The existing zip has a JLCPCB name but holds
   standard Gerber X2 and Excellon files, which PCBWay reads unmodified.
2. BOM: `fab/BOM_PCBWay.csv`.
3. Pick and place: `fab/NeuralCard-cpl.csv`, 61 placements, matching the BOM exactly.
4. Board specs: 85.6 by 54 mm, 2 layer, 1.6 mm FR-4, HASL or ENIG.
5. Assembly on both sides. LEDs on top, everything else on the bottom. One through
   hole part (BT1) plus the mixed SMD and through hole legs on J2 and SW3.
6. Stencil: yes, needed for the LGA-14 at U2 whoever assembles it.

Ask them to confirm the U3 and U4 lines specifically before the order is built,
since those are the two where their answer changes which part gets placed.

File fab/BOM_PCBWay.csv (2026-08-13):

Item | Designator | Qty | Manufacturer Part Number | Manufacturer | Description | Package | Type | Preferred Supplier | Supplier Part Number | Approved Alternate | Remarks
1 | U1 | 1 | ESP32-S3-WROOM-1-N8R2 | Espressif Systems | Wi-Fi + BLE module, 8MB flash, 2MB PSRAM, 3.3V | WIRELM-SMD_ESP32-S3-WROOM-1 | SMD | Digi-Key / Mouser / LCSC | C2913204 | ESP32-S3-WROOM-1-N16R8 | Do not substitute a different antenna variant - PCB antenna keepout is designed for the -1 (PCB ant) module, not -1U (IPEX)
2 | U2 | 1 | LSM6DS3TR-C | STMicroelectronics | 6-axis IMU, accel + gyro, I2C/SPI, 1.71-3.6V | LGA-14_L3.0-W2.5-P0.50-TL | SMD | Digi-Key / Mouser / LCSC | C967633 |  | 0.5mm pitch LGA-14. Stencil required. No substitute - firmware uses this WHO_AM_I and register map
3 | U3 | 1 | ME6211C33M5G-N | Nanjing Micro One Elec | LDO regulator 3.3V 500mA, SOT-23-5 | SOT-23-5_L3.0-W1.7-P0.95-LS2.8-BL | SMD | LCSC / Shenzhen local | C82942 | AP2112K-3.3TRG1 (Diodes Inc) | China-market part, not stocked at Digi-Key/Mouser. If sourcing from a Western distributor use AP2112K-3.3TRG1 - identical SOT-23-5 pinout (1 VIN, 2 GND, 3 EN, 4 NC, 5 VOUT), 600mA
4 | U4 | 1 | ST25DV04KC-IE6S3 | STMicroelectronics | Dynamic NFC/RFID tag, 4-Kbit EEPROM, 13.56MHz ISO15693, I2C | SO-8_L4.9-W3.9-P1.27-LS5.9-BL | SMD | Digi-Key / Mouser / LCSC | C3304276 | ST25DV04K-IER6S3 | This matches the schematic and is the ACTIVE part. The alternate ST25DV04K is the older die, marked NRND by ST but still deeply stocked (38k+ at Mouser), same SO-8 and same pinout - accept it only if the KC cannot be quoted
5 | U5 | 1 | USBLC6-2SC6 | STMicroelectronics | ESD protection array, 2-line, USB, SOT-23-6 | SOT-23-6_L2.9-W1.6-P0.95-LS2.8-BL | SMD | Digi-Key / Mouser / LCSC | C7519 |  | Widely stocked at all distributors
6 | Q1 | 1 | AO3401A | Alpha & Omega Semiconductor | P-channel MOSFET, -30V -4A, SOT-23 | SOT-23_L2.9-W1.3-P1.90-LS2.4-BR | SMD | Digi-Key / Mouser / LCSC | C15127 | DMG2301L (Diodes Inc) | Isolates the coin cell while VBUS is present. Any -30V P-FET in SOT-23 with Vgs(th) below 1.5V is acceptable
7 | BT1 | 1 | CR2032-BS-6-1 | Q&J / MYOUNG | CR2032 coin cell holder, through-hole | BAT-TH_CR2032-BS-6-1 | THT | LCSC / Shenzhen local | C70377 |  | Footprint-specific: pin spacing matches this exact holder. Do NOT substitute a different CR2032 holder without checking the land pattern. Battery cell NOT included in the order
8 | J2 | 1 | TYPE-C-31-M-12 | Korean Hroparts Elec (HRO) | USB Type-C receptacle, 16P, USB2.0 + power, SMD with THT shield legs | USB-C_SMD-TYPE-C-31-M-12_1 | SMD+THT | LCSC / Shenzhen local | C165948 |  | Extremely common China-market USB-C part. Footprint is specific to this 16P body - no substitute without land pattern review
9 | SW1,SW2 | 2 | TS-1187A | XKB Connectivity | Tactile switch SPST-NO, 5.1x5.1mm, 1.5mm height, SMD | SW-SMD_4P-L5.1-W5.1-P3.70-LS6.5-TL_H1.5 | SMD | LCSC / Shenzhen local | C318884 |  | BOOT (SW1) and RESET (SW2). Any 5.1x5.1mm 4-pad tact with 3.7mm pitch fits
10 | SW3 | 1 | MSK12C02 | Shouhan | SPDT slide switch, right-angle, 8x2.8mm, 4 shield tabs | SW_SPDT_Shouhan_MSK12C02 | SMD+THT | LCSC / Shenzhen local | C431540 |  | Power on/off in series with the coin cell. Has 2x 0.85mm NPTH alignment pegs - board is drilled for them
11 | C1,C2,C3,C4,C5,C11 | 6 | CL10B104KB8NNNC | Samsung Electro-Mechanics | 100nF +/-10% 50V X7R ceramic capacitor | 0603 | SMD | Any / PCBWay house stock | C14663 | Any 100nF 50V X7R 0603 | Generic decoupling - house part is fine, X7R or better
12 | C6,C7 | 2 | CL10A105KA8NNNC | Samsung Electro-Mechanics | 1uF +/-10% 25V X5R ceramic capacitor | 0603 | SMD | Any / PCBWay house stock | C128624 | Any 1uF 16V+ X5R 0603 | LDO input and output caps
13 | C8 | 1 | CL21A106KAYNNNE | Samsung Electro-Mechanics | 10uF +/-10% 25V X5R ceramic capacitor | 0805 | SMD | Any / PCBWay house stock | C15850 | Any 10uF 16V+ X5R 0805
14 | C9,C10 | 2 | CL21A226MAYNNNE | Samsung Electro-Mechanics | 22uF +/-20% 25V X5R ceramic capacitor | 0805 | SMD | Any / PCBWay house stock | C45783 | Any 22uF 10V+ X5R 0805 | ESP32-S3 Wi-Fi burst reservoir
15 | C12 | 1 | CC0603JRNPO9BN680 | YAGEO | 68pF +/-5% 50V C0G/NP0 ceramic capacitor | 0603 | SMD | Any / PCBWay house stock | C28262 | Any 68pF C0G 0603 | NFC antenna tuning cap. MUST be C0G/NP0, not X7R. Design target 62pF, acceptable window 56-68pF - may be swapped after VNA measurement
16 | D1-D24 | 24 | KT-0603R | Hubei KENTO Elec | Red LED 0603, 620-625nm, 2.0-2.2Vf @ 20mA | LED-SMD_L1.6-W0.8-R-RD | SMD | LCSC / Shenzhen local | C2286 | Any red 0603 LED, Vf 2.0-2.2V | All 24 must be the SAME part number and bin - these display neural activations by relative brightness, so mixed bins will read as wrong activations
17 | R1,R2,R3,R4,R5,R6 | 6 | 0603WAF2200T5E | UNI-ROYAL (Uniroyal Elec) | 220 ohm +/-1% 1/10W thick film resistor | 0603 | SMD | Any / PCBWay house stock | C22962 | Any 220R 1% 0603 | Charlieplex current limiting - keep all six identical
18 | R7,R8 | 2 | 0603WAF5101T5E | UNI-ROYAL (Uniroyal Elec) | 5.1k ohm +/-1% 1/10W thick film resistor | 0603 | SMD | Any / PCBWay house stock | C23186 | Any 5.1k 1% 0603 | USB-C CC1/CC2 pulldowns (Rd) - value is fixed by the USB-C spec, do not substitute 5.6k
19 | R9,R10 | 2 | 0603WAF1002T5E | UNI-ROYAL (Uniroyal Elec) | 10k ohm +/-1% 1/10W thick film resistor | 0603 | SMD | Any / PCBWay house stock | C25804 | Any 10k 1% 0603 | EN and IO0/BOOT pull-ups
20 | R11,R12 | 2 | 0603WAF4701T5E | UNI-ROYAL (Uniroyal Elec) | 4.7k ohm +/-1% 1/10W thick film resistor | 0603 | SMD | Any / PCBWay house stock | C23162 | Any 4.7k 1% 0603 | I2C SDA/SCL pull-ups
21 | R13,R14 | 2 | 0603WAF1003T5E | UNI-ROYAL (Uniroyal Elec) | 100k ohm +/-1% 1/10W thick film resistor | 0603 | SMD | Any / PCBWay house stock | C25803 | Any 100k 1% 0603 | Q1 gate pulldown and NFC_GPO pull

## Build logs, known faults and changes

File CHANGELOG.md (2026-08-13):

# NeuralCard: Changelog

Hardware revisions and fab-affecting fixes. Newest first.

## v2.3.1-s

Sponsorship build, prepared for assembly by PCBWay. No copper changed.

- **Part libraries renamed to be vendor neutral.** `JLC.pretty`, `JLC.3dshapes`,
  and `JLC.kicad_sym` are now `Parts.pretty`, `Parts.3dshapes`, and
  `Parts.kicad_sym`, with the library nickname changed from `JLC` to `Parts`
  across the schematic, the board, both library tables, the netlist, and the
  model paths inside every footprint. The names carry no fab branding in either
  direction, so nothing says PCBWay either. `fab/NeuralCard_JLCPCB.zip` became
  `fab/NeuralCard_gerbers.zip`, since that is the file uploaded to whichever fab
  builds it. All 3D models still resolve and the board renders.
  `fab/BOM_JLCPCB.csv` keeps its name: it genuinely is the JLCPCB-format
  upstream BOM, and renaming it would make it misleading.

- **Sourcing fields added to the design.** Every one of the 61 placed parts in
  both the schematic and the board carries three new hidden fields: `Alt MPN`,
  `Alt Mfr`, and `Sourcing`. The last one names the buying channel and the
  substitution rule, so the decision travels with the design rather than living
  only in a spreadsheet. Fields are hidden text on the fab layer and touch no
  copper.
- **BOM rewritten for PCBWay.** `fab/BOM_PCBWay.csv` replaces LCSC part codes
  with manufacturer part numbers, since PCBWay buys from Digi-Key, Mouser,
  Farnell, Arrow, Avnet and local Shenzhen distributors, not the JLCPCB parts
  library. `fab/BOM_JLCPCB.csv` is unchanged for comparison.
- **U4 realigned with the schematic.** The old fab BOM asked for
  ST25DV04K-IER6S3 while the schematic specified ST25DV04KC-IE6S3. The KC is the
  active part and the K is marked NRND by ST, so the new BOM follows the
  schematic and lists the K only as a fallback. The substitution had been made
  at order time for LCSC stock reasons that do not apply here.
- **Alternates found for two sole-source parts.** U3 (ME6211C33M5G-N, which no
  Western distributor carries) gets AP2112K-3.3TRG1, pin-identical in SOT-23-5.
  J2 gets XKB U262-161N-4BVC11, verified drop-in by measuring the land patterns:
  NPTH pegs and shield legs agree to within 0.01 mm and the shield row spacing is
  identical at 4.18 mm.
- Verified after: DRC 0 violations, 0 unconnected; ERC 0 violations. Netlist
  unchanged.

Reasoning and per-part status in `docs/SOURCING.md`.

---

## v2.3.1

Audit against the "6 common PCB design mistakes" checklist, two findings fixed.

- **Sharp corners eliminated.** Four acute trace vertices (three 45-degree, one
  83-degree) chamfered; a fifth "0-degree corner" turned out to be a duplicate
  track left by the power-repair routing and was deleted. Zero corners below
  90 degrees remain.
- **U1 decoupling fixed.** C2 relocated from 11.1 mm to 2.8 mm from the
  ESP32's power pin, sitting directly beside pins 1 and 2. C2 was a leaf
  component - a dead-end +3V3 stub plus a 16 mm ground bridge - so the move
  cost nothing and let 6 track segments and 4 vias be deleted outright.
  No schematic change: same 100 nF between the same two nets.
- Verified after: DRC 0 violations, 0 unconnected, every net a single
  connected cluster. Fab files, CPL and renders regenerated.

Full findings and remaining backlog in `docs/PCB-AUDIT.md`.

---

## [Unreleased]: branch `fix/sw3-msk12c02-footprint`

### Changed: repository reorganized into folders (2026-08-03)

Root shrank from 18 loose files to `README.md`, `CHANGELOG.md`, `LICENSE` and four
directories:

| Directory | Contents |
|---|---|
| `hardware/` | KiCad project (`.kicad_pro/sch/pcb`), symbol libs, `.pretty` footprints, lib tables, `board_outline`, `qr_matrix.json` |
| `fab/` | Release deliverables, now including `BOM_JLCPCB.csv` |
| `docs/` | `DESIGN.md`, `BOM.md`, schematic PDF |
| `render/` | Board renders |

The KiCad project moved as a unit, so every `${KIPRJMOD}` library reference is untouched.
All moves are git renames, history follows each file. Doc links, `.gitignore` anchors and
the fab export path updated to match. Verified from the new layout: ERC 0 errors /
41 warnings, DRC 0 violations, identical to before the move.

The untracked generation scripts moved to `hardware/` + `hardware/tools/` beside the files
they operate on (they derive paths from their own location, so they keep working).

## [v2.2.2]: 2026-08-03

Closes out the two items left open at v2.2.1 and syncs the silkscreen with the release tag.

### Fixed: isolated GND pour islands: 27 → 0 (`isolated_copper`)

The v2.2 regression, resolved at its root. the pour stitching step relaxed the pours to
AREA-mode island removal so candidate islands survive long enough to receive a stitching
via, but never restored the strict mode, so every island it couldn't reach stayed isolated
copper forever. It now restores `ISLAND_REMOVAL_MODE_ALWAYS` after the loop converges and
refills: via-stitched islands are connected and survive; unreachable orphans are purged.

**DRC: 0 violations.** The 5 remaining unconnected notices are same-net GND zone fragments,
identical in kind and count to the v2.1 baseline.

### Fixed: R14 edge clearance (`PM-002`)

Moved 52.3 → 51.9 mm, putting its courtyard past the 1.0 mm handling/depaneling
recommendation. Also cleared the silk-edge-clearance warning that its reference designator
caused. Zero PM-002 findings remain.

### Fixed: silkscreen version now matches the release

v2.2.1 shipped with `v2.2` on the silk. The board now reads **v2.2.2**, matching the tag.

### Verification

- **100% routed**, freerouting score 995.19, zero unrouted
- **DRC: 0 violations** (v2.1: 9 · v2.2: 29 · v2.2.1: 28 · **v2.2.2: 0**)
- PCB analyzer: **0 errors, 1 warning**, `TE-001` test points, N/A for a business card
- 642 tracks, 83 vias; CPL 52 placements, fiducials excluded
- Netless-by-design pads: 10 (ANT1 escape, SW3 2×NPTH + 4×SH, 3 fiducials)

---

## [v2.2.1]: 2026-08-03

Two findings from the first full analyzer run against the *v2.2* board. Both were real; one
was a genuine footprint defect the earlier "probably an artifact" call had half-right.

### Fixed: the NFC coil footprint had no courtyard (`PM-002`)

The coil footprint carried `allow_missing_courtyard`, so placement checkers
had nothing to measure and fell back to the footprint origin at (0, 0), the board corner,
reporting **"ANT1 is 0.0 mm from board edge"**. The coil copper actually sits 2.65 mm inboard.

The reading was wrong but the cause was a real defect: a footprint without a courtyard can't
be collision-checked. Now emits a `B.CrtYd` box around the drawn extent plus the standard
0.25 mm margin. C12 moved 13.4 → 12.9 mm, since the new courtyard clipped its by 0.1 mm.

### Fixed: no fiducials (`FD-001`)

Three `Fiducial_1mm_Mask2mm` targets on B.Cu at (3.5, 3.0), (3.5, 50.5) and (81.0, 50.5),
an L pattern, asymmetric so the placement machine cannot mistake board orientation. Excluded
from BOM and CPL, so the placement count stays 52. Justified by the 0.28 mm minimum pad on
the LGA-14 IMU.

### Verification

- **100% routed**, freerouting score 995.36, zero unrouted
- **PCB analyzer errors: 0** (was 2). Findings 13 → 11; both remaining are warnings
- 586 tracks; DRC 0 clearance, 0 crossing, 0 courtyard-overlap violations
- Isolated GND pour islands **28 → 27**, still the open regression from v2.2
- CPL 52 placements, fiducials correctly excluded

### Still open

`PM-002` R14 at 0.95 mm from the board edge (0.05 mm under the 1.0 mm recommendation) and
`TE-001` test-point coverage, which does not apply to a business card. `LR-001` still fires
24 times on the charlieplex matrix it misreads.

---

## [v2.2]: 2026-08-02

Board revision driven by the kicad-happy analysis. **The headline is decoupling.**

### Fixed: decoupling capacitors were 25 mm from the ICs they serve

Placement dealt every passive into two cosmetic edge rows by list order, ignoring which
IC each cap belonged to. The caps were correctly wired and completely ineffective:

| IC | v2.1 | v2.2 |
|---|---|---|
| U1 ESP32-S3 | **24.8 mm** | 11.4 mm |
| U2 IMU | 10.8 mm (its own C5 was **42 mm** away) | **4.0 mm** |

Neither ERC nor DRC can see this, connectivity was always correct. C1/C2 now flank the
module, C3/C4/C8 sit in the 6 mm corridor beside it (rotated 90° to fit), C5 is 4 mm from the
IMU. C9/C10 (22 µF ride-out, not HF) stay in the edge row; keeping them out of the corridor
is what let the output-column charlieplex lines route.

### Fixed: SW3 was missing from the placement table

Added by hand in `b2ccb56`, it never entered the placement data, so this re-place would have
dropped it to the default centre slot and silently undone the DFM fix. Now pinned at
81.455, 28.0, rotated -90.

### Fixed: stale internal paths (2026-08-03)

Local tooling referenced a directory the project no longer lives in; corrected.

### Changed: v2.1 → v2.2 on the silkscreen, fab package and renders regenerated

### Verification

- **100% routed**, freerouting score 995.36, zero unrouted connections
- **0 unconnected pads.** The 7 reported are netless by design: ANT1's escape, SW3's two NPTH
  holes and four shield tabs
- 631 tracks, 79 vias (v2.1: 465 / 57)
- ERC 0 errors / 41 warnings; DRC 0 clearance and 0 crossing violations
- CPL still 52 placements; SW3 at 81.4550, -28.0000, Bottom, -90

**Known regression:** isolated GND pour islands went from 5 to 28. Redundant copper the
stitcher can't reach with a via; every GND pad is track-routed, so it is cosmetic rather than
functional. stitching converges there. Worth revisiting before a production run.

**Not fixed in v2.2:** `FD-001` (no fiducials), `DFM-001`/`DFM-002` (0.1 mm annular ring below
IPC Class 2), `PU-001` (INT2 pull-up, the pin is unused). Thermal analysis still SKIPPED: it
needs datasheet PDFs in an extraction cache, and LCSC serves no datasheet URLs for these parts.

**This supersedes the v2.1 fab package.** Order SMT026072863054 was placed against v2.1.

---

### Removed: internal tooling untracked (2026-08-02)

Local build tooling is no longer distributed with the repository; the published design is
the committed `NeuralCard.kicad_sch` and `NeuralCard.kicad_pcb`. The README section that
documented a rebuild-from-source workflow was removed with it, since the repo no longer
ships what it described. Editing the design means editing the KiCad files directly.

### Removed: automated design review CI (2026-08-02)

Dropped the review workflow, its render script and `docs/design-review.md`. The workflow worked, it ran clean on both a PR and a push, and
committed its own refresh, but it added a bot commit loop and a generated section to a repo
whose value is the board, not its CI.

**The mermaid diagrams stay.** They are hand-authored, not tool output, and they are the part
that helps someone landing on the repo. The three descriptive badges stay; the workflow-status
badge went with the workflow.

The two real fixes the review surfaced (`RS-001`, LED `Value`) are already merged and remain.
Findings recorded for later: `SS-001` (0% MPN coverage), `DFM-001`/`DFM-002` (0.1 mm annular
ring, below IPC Class 2), `FD-001` (no fiducials).

### Changed: board renders regenerated (2026-08-02)

`render/NeuralCard_front_v21.png` and `_back_v21.png` were last updated in `b2ccb56`
(22 Jul), one PCB commit **before** the SW3 footprint swap in `a316055` (31 Jul), so the
published images still showed the old improvised switch land. Regenerated from the current
board with `kicad-cli pcb render` at 1568×1040, transparent background, matching the previous
framing. SW3 now appears with its correct MSK12C02 body.

### Changed:.gitignore expanded (2026-08-02)

Rebased on [github/gitignore's KiCad.gitignore](https://github.com/github/gitignore/blob/main/KiCad.gitignore).
Adds KiCad backup/autosave patterns (`*.bak`, `*.kicad_sch-bak`, `_autosave-*`, `*-save.*`),
ERC and cache-library output, Python artifacts (`__pycache__/`, `*.py[cod]`, `.venv/`),
3D exports (`*.step`), superseded fab snapshots (`fab.old-*/`), and editor/OS noise. This
takes `JLC.bak` and `fab.old-jul22/` out of the working tree's untracked list.

Deliberately still tracked: `BOM_JLCPCB.csv` and `fab/*.csv` are release deliverables uploaded
to JLCPCB, not incidental KiCad exports, and the generator scripts are the design source,
see README, "The board is generated, not drawn."

### Added: automated design review in CI (2026-08-02, removed same day)

`.github/workflows/design-review.yml` runs [kicad-happy](https://github.com/aklofas/kicad-happy)
against the schematic and PCB. On a PR it posts a diff-only comment (just what that PR
changed); on `main` it refreshes the README summary and commits the full report to
`docs/design-review.md`. SPICE is disabled, no ngspice on the runner and nothing analog here.

A render step turned the analyzer JSON into the README block. It grouped findings
by `rule_id`, so a detector that fires 24 times is one row rather than 24, and applies a
suppression list with a stated reason per rule instead of silently dropping anything.

`README.md` gains four badges and a **How it's wired** section with two mermaid diagrams,
the power path through SW3, and the 6→8→10 inference path. Coloured from the PatternFly
palette, matching the Red Hat faces already plotted on the silkscreen (§Typography).

**Baseline: 81 findings, 3 errors, 5 warnings, 49 info after suppression.**

One suppression matters. `LR-001` fires once per LED claiming no current-limiting resistor,
which is wrong: the matrix is charlieplexed, so R1, R6 limit current on the six shared GPIO
drive lines. Left in, it would be 89% of the error count. Note that `LA-AUD` tags the same
LEDs `[resistor_limited]`, so the toolchain contradicts itself here.

Findings worth acting on, recorded but not yet fixed: `SS-001` (0% MPN coverage, the root
cause of the SW3 drift), `DFM-001`/`DFM-002` (0.1 mm annular ring, below IPC Class 2's
0.125 mm), and `FD-001` (no fiducials, with 0.28 mm minimum pad on the LGA-14 IMU).
`PM-002`'s "ANT1 is 0.0 mm from board edge" is almost certainly the net-tie footprint origin
rather than copper, the coil sits at x[2.5, 14.5] per §8.

### Fixed: LED value and VBAT source flag (2026-08-02)

Two findings from the first CI-equivalent run, both fixed at the schematic source:

- **`RS-001`, `VBAT` has no declared source.** Fallout from the SW3 symbol: a plain label
  carries no pin type, so strict checkers read the net as undriven. Added a `PWR_FLAG`.
  KiCad's own ERC passed without it; this satisfies the stricter check.
- **LED `Value` said `blue`** while the footprint and fab BOM have always been red. Corrected
  to `red`. Safe to change: the fab BOM is hand-maintained
  and not generated from the schematic, so no fab output moves.

Verified: netlist unchanged on every real pin, **174 schematic pads vs 173 PCB pads, 0
mismatches**, ERC still **0 errors / 41 warnings**. The analyzer now reads
`LED D1 (red) [resistor_limited]` and `RS-001` is gone.

### Fixed: LED part number contradicted the board (2026-08-02)

Found by running [kicad-happy](https://github.com/aklofas/kicad-happy)'s BOM and LCSC skills
against the project.

`BOM.md` listed D1, D24 as **blue** `C72041` while `BOM_JLCPCB.csv`, the PCB footprint
(`LED-SMD_L1.6-W0.8-R-RD`) and `DESIGN.md` §0 all specify **red** `C2286`. Ordering from the
human-facing BOM would have bought the wrong colour for 24 of 52 placements, and the LCSC
check found `C72041` down to **14 units in stock**, so the order would have failed outright.

- `BOM.md` D1, D24 row corrected to `C2286` / KT-0603R.
- Ordering note 2 rewritten: red is the settled v2 decision, not a future suggestion.
- U1 corrected from `N16R8` to **`N8R2`**, the part `C2913204` actually resolves to. This was
  already noted in `DESIGN.md` §8 but never fixed in the BOM table.
- New `BOM.md` §3b records all 14 codes with resolved MPN, stock and unit price
  (parts ≈ **$6.91/board**).

`C431540` independently confirmed as MSK12C02 with ~99k in stock, the SW3 fix holds.

Still outstanding: the schematic's `Value` field for D1, D24 reads `blue`
while the footprint and fab outputs are red. Cosmetic, it does not
reach the netlist or the fab package, but it should be corrected in the generator.

### Fixed: SW3 now exists in the schematic (2026-08-02)

SW3 had been added directly to the layout and had no schematic symbol, so
**Tools → Update PCB from Schematic** would have flagged it as an extra footprint and
deleted it, silently reverting the DFM fix. The board also carried a `VBAT` net with no
schematic counterpart.

Fixed at the schematic source rather than by hand-editing `NeuralCard.kicad_sch`, so the
switch survives the next regeneration:

- `LIBSYMS` gains `Switch:SW_SPDT`, `PIN_XY` its pin geometry, `FP` maps SW3 to
  `Button_Switch_SMD:SW_SPDT_Shouhan_MSK12C02`.
- `section_power()` now routes the coin through the switch: BT1 pin 1 (+) drives `VBAT`,
  SW3 pin 2 (common pole) takes `VBAT`, pin 3 (closed throw) drives `+3V3`, and pin 1
  (open throw) carries an explicit no-connect.

KiCad's generic `Switch:SW_SPDT` numbers its common pole **pin 2**, which matches the
MSK12C02 pinout and the pad nets already on the board, so no custom symbol was needed and
no pin renumbering was involved.

Net changes, and nothing else moved:

| Net | Before | After |
|---|---|---|
| `+3V3` | `BT1.1` … | `SW3.3` … (coin no longer feeds the rail directly) |
| `VBAT` | did not exist in schematic | `BT1.1`, `SW3.2` |
| `SW3.1` |: | unconnected (open throw, no-connect flagged) |

**Verification.** Schematic netlist checked pad-by-pad against `NeuralCard.kicad_pcb`:
**174 schematic pads, 173 PCB pads, 0 net mismatches**, the one difference is SW3 pad 1,
unconnected on both sides. Update PCB from Schematic is now a connectivity no-op. ERC: **0
errors, 41 warnings**, identical to the count before this change (all 41 are the benign
`pin_to_pin` notices inherent to easyeda2kicad-imported symbols).

The generator was also confirmed to reproduce the previously committed schematic exactly,
53 nets and 53 components, zero differences, before the switch was added, so regenerating
loses nothing.

### Fixed: SW3 power switch footprint (`a316055`, 2026-07-31)

JLCPCB rejected SW3 at DFM review on PCBA order **SMT026072863054**: the part they had
selected, **C431540** (SHOU HAN MSK12C02), did not fit the pads on the board.

Root cause: SW3 was added by hand in `b2ccb56` outside the normal design flow, so it
carried an improvised land pattern. The BOM listed the part as
"select-at-order" with a note to verify the footprint against whatever got chosen. That
verification never happened.

| | Before (`b2ccb56`) | After (`a316055`) |
|---|---|---|
| Footprint | `""`: unnamed, hand-drawn land | `Button_Switch_SMD:SW_SPDT_Shouhan_MSK12C02` |
| Value | `""`: empty | `MSK12C02` |
| LCSC part | select-at-order | **C431540** |
| Signal pads | 3× 0.7 × 1.1 mm rect, 1.3 mm pitch | 3× roundrect, per manufacturer datasheet |
| Shield tabs | none | 4× `SH` retention pads |
| Locating holes | none | 2× 0.85 mm NPTH |
| 3D model | Copal DIP switch scaled to 0.62 (placeholder) | `SW_SPDT_Shouhan_MSK12C02.step` |
| Body size assumed | ~3 mm | 8 × 2.8 mm (actual) |

Nothing was going to seat on the original land.

**Orientation and placement.** The MSK12C02 is right-angle, so it is rotated 270° with its
pins facing inboard toward BT1 and the actuator facing the right card edge where a thumb can
reach it. Moved 0.546 mm inboard to leave 1.0 mm from courtyard to board edge for assembly.

**Net mapping, unchanged by this fix.** Pad 2 is the common pole on `VBAT`, pad 3 the closed
throw on `+3V3`, pad 1 the open throw (intentionally netless). Sliding one way ties the coin
to the rail; the other way parks the pole on a floating throw. Standard SPDT-as-on/off.

The four `SH` tabs are deliberately left netless. They are the retention frame, and the
datasheet does not state that the frame is isolated from the contacts, tying them to GND
would risk shorting the coin cell. They still solder down for mechanical retention.

**Verification.** DRC clean under the project rules (0 violations, 0 unconnected). Measured
against the same ruleset, the board carries the same silk-art violation count as before the
change.

**Fab package regenerated.** Both NPTH holes appear in the drill file at X142.111 / Y-62.943
and Y-65.943. CPL places SW3 at 142.1112, -64.4434 rotated -90, Bottom. BOM names C431540
outright instead of select-at-order.

### Added: reproducible fab refresh (`a316055`)

The JLCPCB fab bundle is regenerated in one reproducible pass rather than five remembered
commands, writing Protel-extension gerbers directly with no stray `.gbr` duplicates. The
zip contains gerbers and drill only; BOM and CPL upload separately.

### Added: hardware power switch (`b2ccb56`, 2026-07-22)

SW3 introduced as a physical on/off slide switch in series between the coin cell and the
`+3V3` rail, alongside ground repairs and a DRC cleanup. This supplements, it does not
replace, the firmware deep-sleep power-button behavior on SW1/GPIO0 described in
`DESIGN.md` §8.

Added directly to `NeuralCard.kicad_pcb` without a matching schematic symbol. See Known
Issues.

---

## Known issues

Open as of 2026-08-02.

### Resolved on this branch

- **SW3 missing from the schematic**, fixed above; schematic and PCB now agree on every pad.
- **KiCad 10 re-save drift**, `NeuralCard.kicad_sch` and `JLC.kicad_sym` had ~15,000 lines
  of uncommitted working-tree changes from a KiCad 10 re-save (format `20250114`→`20260306`,
  eeschema 9.0→10.0, paper A2→A3). Discarded on 2026-08-02; the schematic is back to the
  generator's canonical KiCad 9 / A2 output. **Open the project in KiCad 9, or decline the
  format-upgrade prompt in KiCad 10**, or the drift returns the moment the file is saved.

### 1. Documentation drift predating this branch

`BOM.md` sections 1 to 2 and `DESIGN.md` §3 still describe the v2-removed USB-C power path
(J1, D0, U3 LDO, Q1 P-FET, R7/R8 CC resistors, R13 bleeder, C6/C7). Those nine parts are
absent from the current CPL. `DESIGN.md` §0 records the removal but the downstream sections
were never updated. Out of scope for this branch.

---

## Current placement count

52 placements per `fab/NeuralCard-cpl.csv`:

| Group | Refs | Qty |
|---|---|---|
| Neuron LEDs | D1: D24 | 24 |
| Resistors | R1: R6, R9: R12, R14 | 11 |
| Capacitors | C1: C5, C8: C12 | 10 |
| Switches | SW1, SW2, **SW3** | 3 |
| ICs / module | U1, U2, U4 | 3 |
| Coin holder | BT1 | 1 |

Only non-soldered item remains the CR2032 coin itself.

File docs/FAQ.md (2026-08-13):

# NeuralCard FAQ

Answers to the questions people actually ask about this board. Everything here
refers to hardware revision v2.3.

---

### What does the card actually do?

You hold it, air-write a digit (0-9), and a neural network running on the card
classifies the gesture. The 24 LEDs on the front are drawn as a network of
neurons - the output column on the right edge lights up with the network's
answer, brightest neuron wins. Tap a phone on the NFC area and it opens a
contact page. It is a business card that demonstrates the thing it claims its
owner can do.

### How does it detect the number?

Five stages, all on the card:

1. **Capture** - the LSM6DS3 IMU streams 6-axis motion (accel + gyro) at a few
   hundred Hz. An air-written digit is a ~1.5 s time-series with a distinctive
   shape per digit.
2. **Segmentation** - the IMU's motion interrupt wakes the ESP32; recording
   runs until the motion stops.
3. **Preprocessing** - gravity is subtracted, the gesture is resampled to a
   fixed length and normalised, so a big slow "7" and a small quick "7" look
   alike.
4. **Inference** - a small quantised network (1D-CNN or MLP, tens of thousands
   of parameters, trained offline on recorded gestures) turns ~600 input
   numbers into 10 output scores. The ESP32-S3's vector instructions run this
   in milliseconds.
5. **Display** - softmax confidences map to LED brightness on the 0-9 output
   column. 80% sure it's a 3 means LED "3" blazes and "8" glimmers.

Nothing on the card "knows" what a 3 is - the network is just trained weights,
and detection is a matrix multiplication small enough for a coin cell.

### What battery does it take?

A single CR2032 lithium coin cell, plus-side facing out, held in the
CR2032-BS-6-1 clip on the back. The slide switch (SW3) next to it is the power
switch. The battery is not rechargeable and the board never attempts to charge
it - see the next answer.

### Does it only work on the coin cell? What can't it do on battery?

Three power states, three capability levels:

| | No power | CR2032 | USB-C |
|---|---|---|---|
| NFC tap-to-share | **yes** | yes | yes |
| Gestures + inference + LEDs | no | **yes** | yes |
| Flashing / serial | no | no | **yes** |
| WiFi / Bluetooth | no | no | yes |
| Full LED brightness | no | limited | yes |

The NFC chip is a passive tag powered by the reading phone's own radio field,
so the business-card function works with the battery dead or missing.

The coin cell's limit is internal resistance, not capacity: it delivers
10-30 mA comfortably, sags on spikes. Inference at reduced CPU clock fits;
a WiFi transmit burst (300 mA+) collapses the rail and resets the chip. Radio
features are therefore USB-only by physics, not by policy.

When USB-C is plugged in, a P-FET (Q1) disconnects the battery entirely -
USB can never back-feed or charge the cell.

### Can I program it over USB-C?

Yes - that is the point of v2.3. The USB-C data pair is routed to the
ESP32-S3's native USB-Serial-JTAG, so a plain USB-C cable gives you flashing
and a serial console with no adapter. First-time flash of a blank board:
hold BOOT, tap RST, release BOOT (also printed on the silk). After the first
firmware, esptool resets it automatically.

Note the corollary: initial flashing is the one thing that strictly requires
the USB port. A blank ESP32 cannot be programmed by battery wishes or NFC.

### Why only 6 pins for 24 LEDs?

Charlieplexing. Each LED only conducts for one specific pair-and-polarity of
the six charlieplex lines (CHX1-6 through the 220R resistors), so n pins drive
n*(n-1) LEDs - 6 pins cover up to 30. The firmware scans fast enough that
persistence of vision turns one-at-a-time flashes into a steady image, and
per-LED duty cycle becomes brightness. It is also why the display is
coin-cell-viable: only one LED is ever actually on.

### What does it cost to build?

Two routes (5-board quantities, 2026 prices):

- **Hand assembly**: ~$9 for PCBs + solder-paste stencil from JLCPCB, ~$77 of
  parts from LCSC (spare-heavy quantities - the floor is ~$60). About a third
  of the parts cost is the five ESP32-S3 modules alone. Passives are
  essentially free: ~700 resistors and capacitors cost about $8.
- **Factory assembly**: ~$168 extra at JLCPCB for 5 boards, of which ~$100 is
  fixed setup/feeder/stencil overhead that would amortise at volume. Rational
  at 30+ boards, not at 5.

The fab files are in `fab/` (gerber zip, BOM with LCSC part numbers, CPL).

### Anything tricky about hand-soldering it?

Two parts. The LSM6DS3 IMU is an LGA-14 at 0.5 mm pitch with pads under the
package - stencil plus hot plate or hot air, an iron alone cannot reach the
joints. The ESP32 module's thermal pad likes hot air too. Everything else is
0603/0805/SOT/SO-8 and iron-friendly. The LEDs go on the front face,
everything else on the back - two paste passes. Buttons and the battery clip
solder last with an iron.

Known substitution: the BOM specifies ST25DV04K-IER6S3 (C155601) for the NFC
chip because the original ST25DV04KC variant is nearly out of stock
everywhere. Same package, same pinout, same function.

### What is C12 and why is its value "tune after VNA"?

C12 parallel-tunes the NFC antenna coil to 13.56 MHz. The right value depends
on the manufactured coil's actual inductance, so the design carries a 68 pF
C0G placeholder inside the calculated 56-68 pF window. Read range is the
practical test: if taps need contact instead of ~2 cm, swap C12 a few pF and
retest. A VNA makes this rigorous; a phone and patience make it possible.

### Does the card need firmware to be useful?

The NFC contact-sharing works from the moment U4 is soldered and programmed
with an NDEF record - no firmware, no battery. Everything else (gestures,
inference, LEDs) is firmware that lives ahead: charlieplex scanner, IMU
streaming, gesture recording, then the trained model. The hardware for every
stage is on the board and verified.

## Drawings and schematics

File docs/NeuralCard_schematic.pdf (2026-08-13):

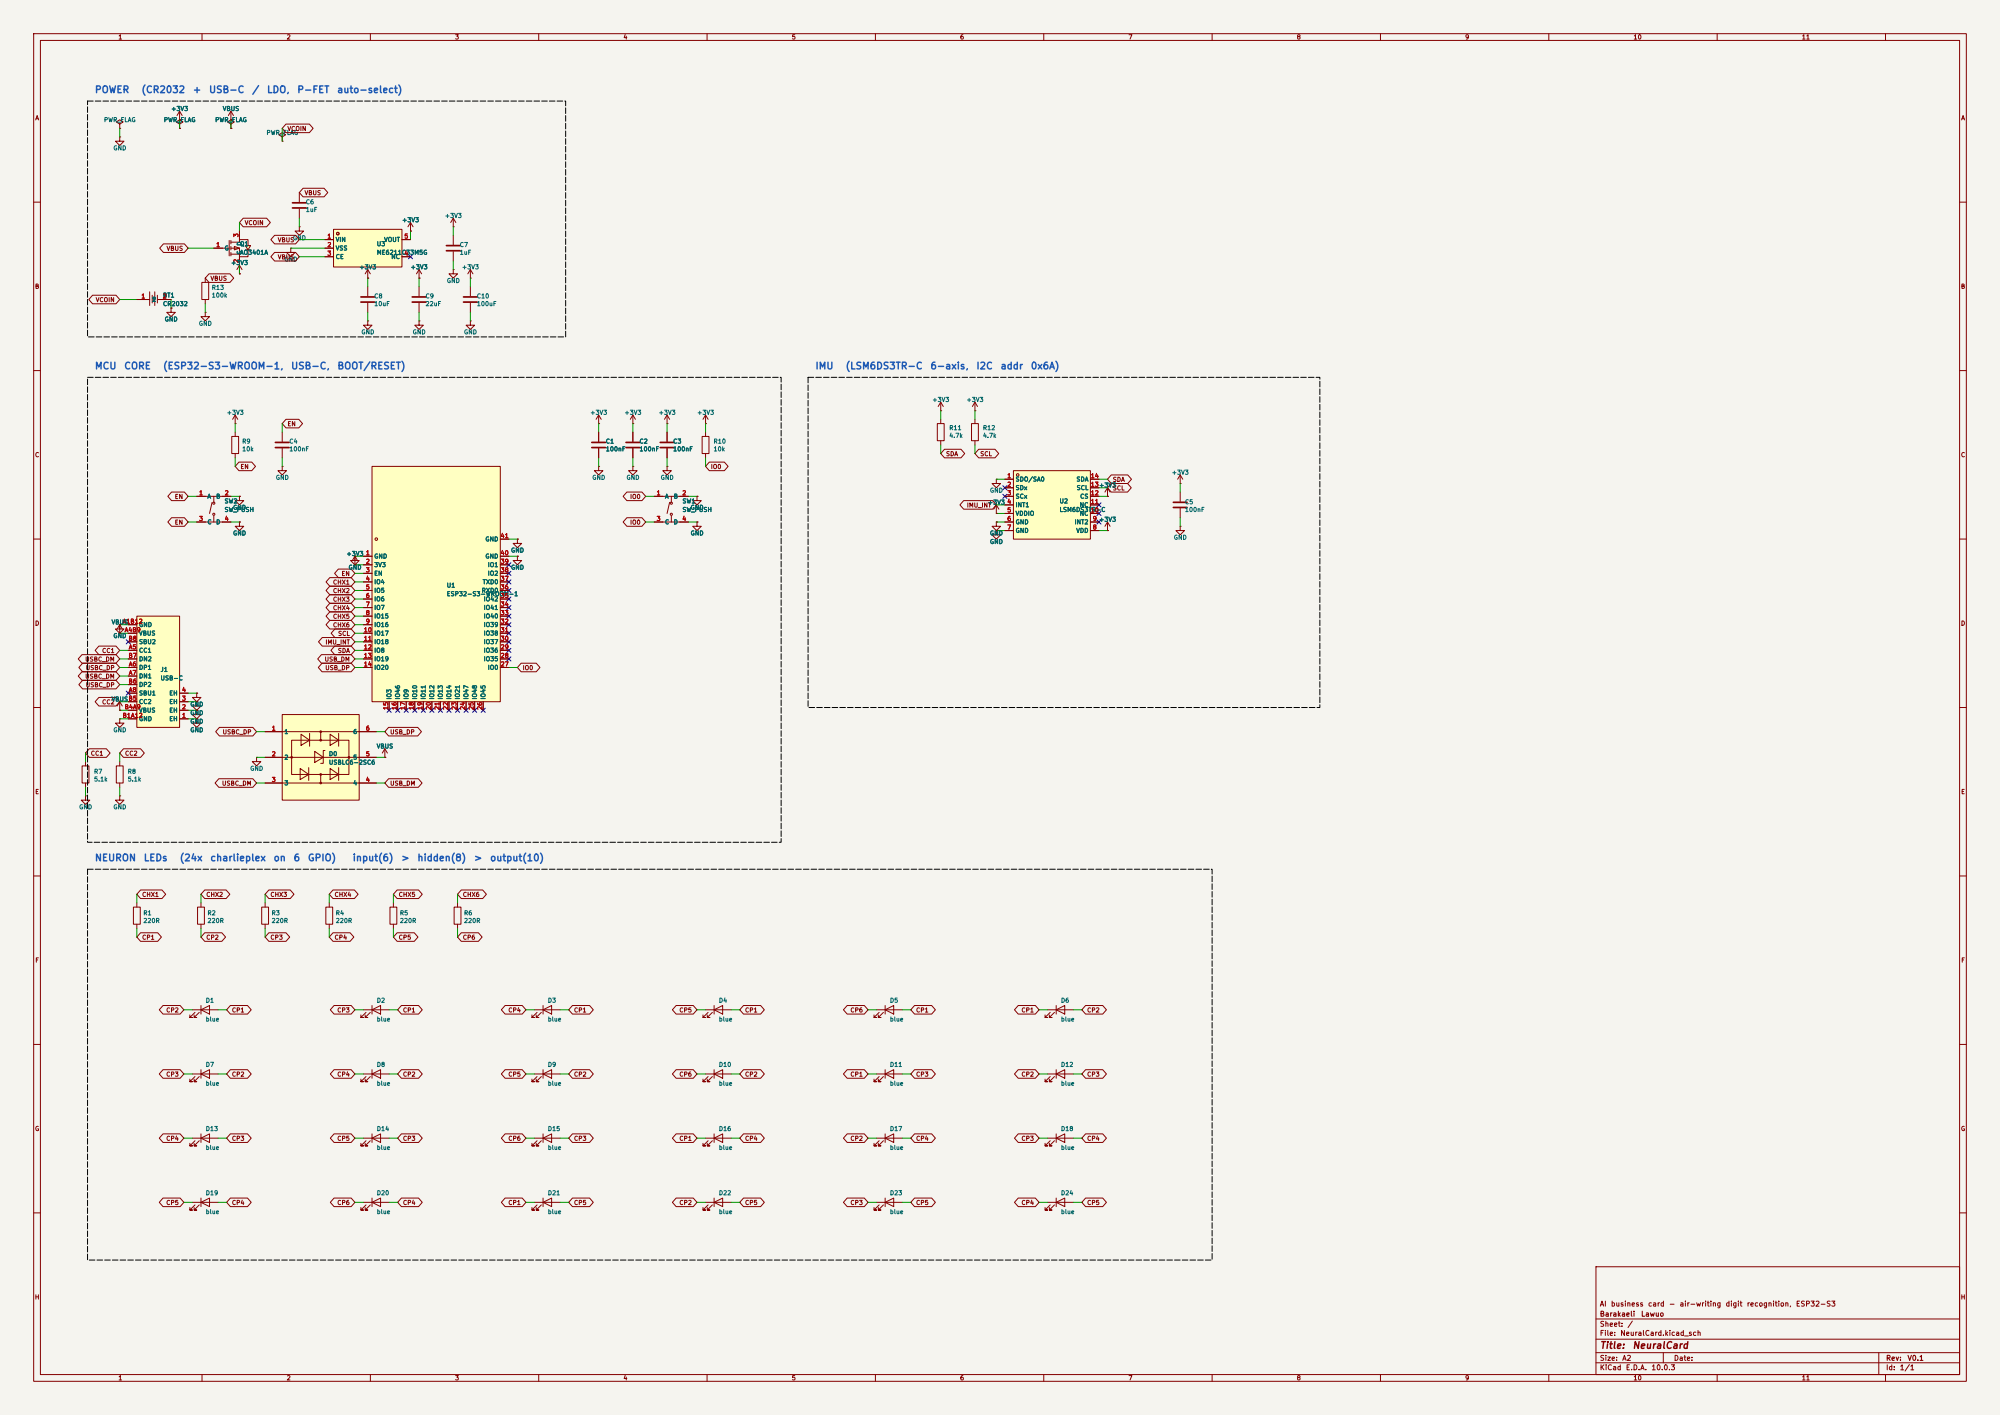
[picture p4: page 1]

POWER (CR2032 + USB-C / LDO, P-FET auto-select)

AI business card - air-writing digit recognition, ESP32-S3
Barakaeli Lawuo
Sheet: /
File: NeuralCard.kicad_sch
Title: NeuralCard

Size: A2 | Rev: V0.1
KiCad E.D.A. 10.0.3 | Id: 1/1

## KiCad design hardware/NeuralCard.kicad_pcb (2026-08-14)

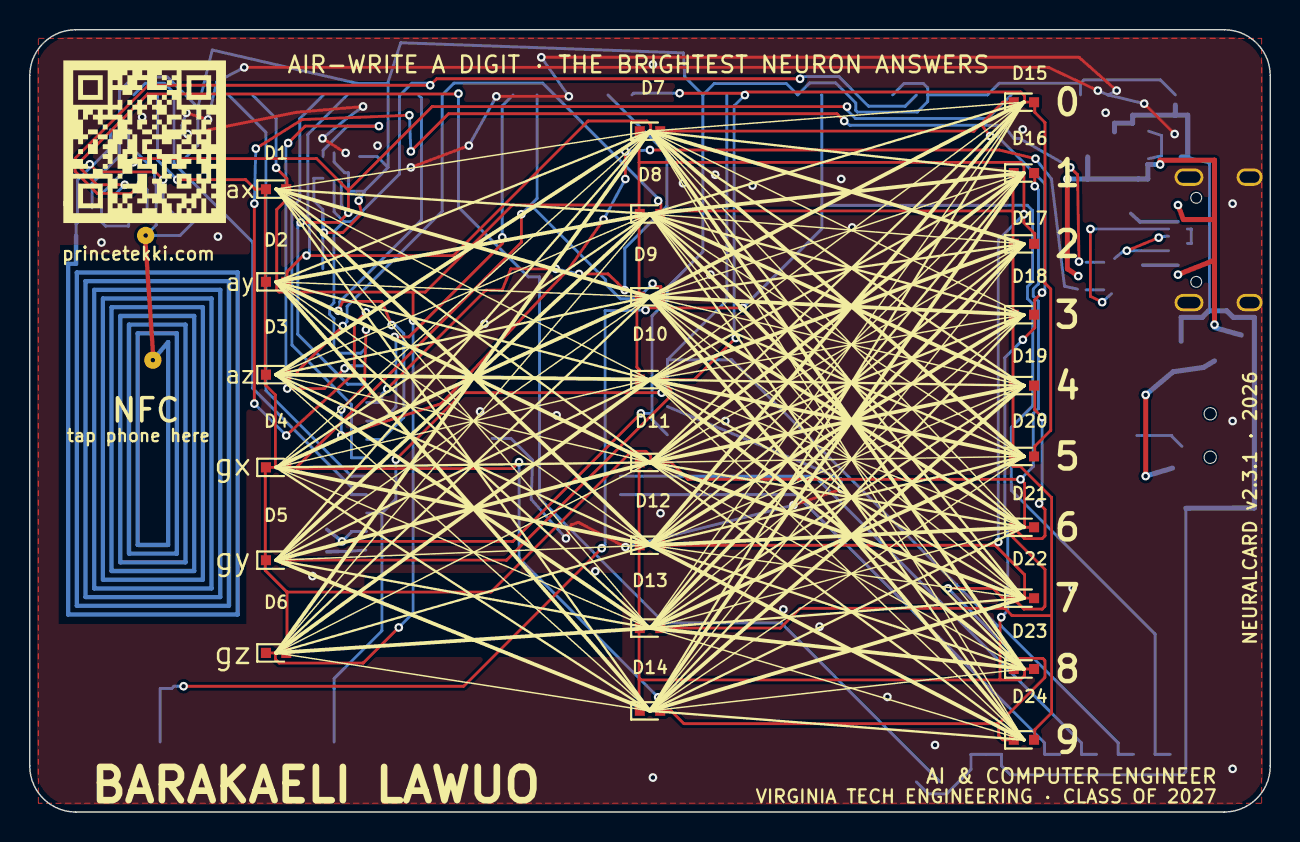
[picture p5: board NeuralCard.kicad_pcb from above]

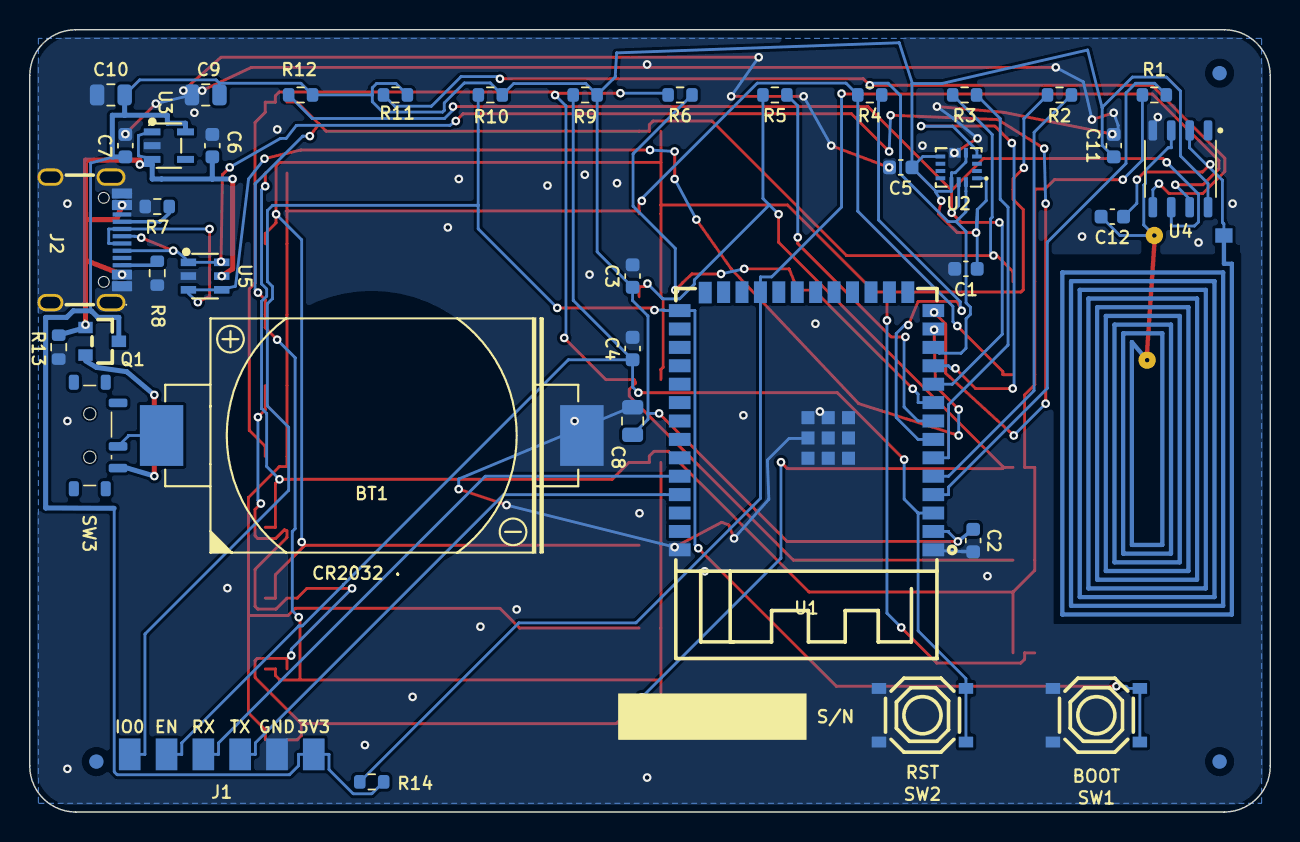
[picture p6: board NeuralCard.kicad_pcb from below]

Board: 2 copper layers, 85.6 x 54.0 mm, 66 parts (42 on the bottom side), 31 nets.

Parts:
ANT1: NFC_COIL; NFC_Antenna_13x24
BT1: BAT-TH_CR2032-BS-6-1
C1, C2, C3, C4, C5, C11, C12: C_0603_1608Metric
C6, C7: 1uF; C_0603_1608Metric
C8, C9, C10: C_0805_2012Metric
D1, D2, D3, D4, D5, D6, D7, D8, D9, D10, D11, D12, D13, D14, D15, D16, D17, D18, D19, D20, D21, D22, D23, D24: LED-SMD_L1.6-W0.8-R-RD
FID1, FID2, FID3: Fiducial_1mm_Mask2mm
J1: ProgPads; ProgPads_1x6
J2: TYPE-C-31-M-12; USB-C_SMD-TYPE-C-31-M-12_1
Q1: AO3401A; SOT-23_L2.9-W1.3-P1.90-LS2.4-BR
R1, R2, R3, R4, R5, R6, R9, R10, R11, R12, R14: R_0603_1608Metric
R7, R8: 5.1k; R_0603_1608Metric
R13: 100k; R_0603_1608Metric
SW1, SW2: SW-SMD_4P-L5.1-W5.1-P3.70-LS6.5-TL_H1.5
SW3: SW_SPDT_Shouhan_MSK12C02
U1: WIRELM-SMD_ESP32-S3-WROOM-1
U2: LGA-14_L3.0-W2.5-P0.50-TL
U3: ME6211C33M5G-N; SOT-23-5_L3.0-W1.7-P0.95-LS2.8-BL
U4: SO-8_L4.9-W3.9-P1.27-LS5.9-BL
U5: USBLC6-2SC6; SOT-23-6_L2.9-W1.6-P0.95-LS2.8-BL

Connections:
+3V3: C1.1, C2.1, C3.1, C5.1, C7.1, C8.1, C9.1, C10.1, C11.1, J1.1, Q1.3, R9.1, R10.1, R11.1, R12.1, R14.1, U1.2, U2.1, U2.5, U2.8, U2.12, U3.5, U4.8
CC1: J2.A5, R7.1
CC2: J2.B5, R8.1
CHX1: R1.1, U1.4
CHX2: R2.1, U1.5
CHX3: R3.1, U1.6
CHX4: R4.1, U1.7
CHX5: R5.1, U1.8
CHX6: R6.1, U1.9
CP1: D1.2, D2.2, D3.2, D4.2, D5.2, D6.1, D11.1, D16.1, D21.1, R1.2
CP2: D1.1, D6.2, D7.2, D8.2, D9.2, D10.2, D12.1, D17.1, D22.1, R2.2
CP3: D2.1, D7.1, D11.2, D12.2, D13.2, D14.2, D15.2, D18.1, D23.1, R3.2
CP4: D3.1, D8.1, D13.1, D16.2, D17.2, D18.2, D19.2, D20.2, D24.1, R4.2
CP5: D4.1, D9.1, D14.1, D19.1, D21.2, D22.2, D23.2, D24.2, R5.2
CP6: D5.1, D10.1, D15.1, D20.1, R6.2
EN: C4.1, J1.5, R9.2, SW2.1, SW2.3, U1.3
GND: BT1.2, C1.2, C2.2, C3.2, C4.2, C5.2, C6.2, C7.2, C8.2, C9.2, C10.2, C11.2, J1.2, J2.1, J2.2, J2.3, J2.4, J2.A1B12, J2.B1A12, R7.2, R8.2, R13.2, SW1.2, SW1.4, SW2.2, SW2.4, U1.1, U1.40, U1.41, U2.6, U2.7, U3.2, U4.4, U5.2
IMU_INT: U1.11, U2.4
IO0: J1.6, R10.2, SW1.1, SW1.3, U1.27
NFC_ANT_A: ANT1.1, C12.1, U4.2
NFC_ANT_B: ANT1.2, C12.2, U4.3
NFC_GPO: R14.2, U1.23, U4.7
RXD: J1.4, U1.36
SCL: R12.2, U1.10, U2.13, U4.6
SDA: R11.2, U1.12, U2.14, U4.5
TXD: J1.3, U1.37
USB_DM: J2.A7, J2.B7, U1.13, U5.3, U5.4
USB_DP: J2.A6, J2.B6, U1.14, U5.1, U5.6
VBAT: BT1.1, SW3.2
VBAT_SW: Q1.2, SW3.3
VBUS: C6.1, J2.A4B9, J2.B4A9, Q1.1, R13.1, U3.1, U3.3, U5.5

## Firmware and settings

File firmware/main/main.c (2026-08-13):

// NeuralCard firmware - bring-up scaffold.
//
// On boot: LED self-test sweep, IMU check, then an idle "thinking" pattern.
// Serial commands (USB-C console, 115200-agnostic):
//   s        stream raw IMU samples as CSV until any key
//   0-9      record one labelled gesture (for the training set)
//   t        LED sweep test
//   w        air-write a digit and classify it (pretrained model)
//   p        print the last stroke the network was shown
#include "freertos/FreeRTOS.h"
#include "freertos/task.h"
#include "charlieplex.h"
#include "lsm6ds3.h"
#include "gesture.h"
#include "infer.h"
#include <stdio.h>
#include <math.h>

static bool imu_ok;

static void sweep(void)
{
    for (int i = 0; i < CP_NUM_LEDS; i++) {
        cp_clear();
        cp_frame[i] = 8;
        vTaskDelay(pdMS_TO_TICKS(60));
    }
    cp_clear();
}

// Idle animation: hidden-layer LEDs breathe softly.
static void idle_tick(int t)
{
    for (int i = 0; i < 15; i++) {
        float ph = (float)t / 30.0f + (float)i * 0.7f;
        cp_frame[i] = (uint8_t)(4.0f + 4.0f * sinf(ph));
    }
}

static void stream_imu(void)
{
    printf("# streaming - press any key to stop\n");
    printf("gx,gy,gz,ax,ay,az\n");
    imu_sample_t s;
    while (getchar() == EOF) {
        if (imu_data_ready() && imu_read(&s))
            printf("%d,%d,%d,%d,%d,%d\n", s.gx, s.gy, s.gz, s.ax, s.ay, s.az);
        vTaskDelay(1);
    }
}

void app_main(void)
{
    printf("\nNeuralCard v2.3 - firmware scaffold\n");

    cp_init();
    sweep();                       // proves every LED and the scan mapping

    imu_ok = imu_init();
    printf("IMU: %s\n", imu_ok ? "OK" : "NOT FOUND - check U2 soldering");

    int t = 0;
    for (;;) {
        int c = getchar();
        if (c == 's' && imu_ok) stream_imu();
        else if (c == 't') sweep();
        else if (c == 'w' && imu_ok) infer_capture_and_classify();
        else if (c == 'p') infer_dump_last_image();
        else if (c >= '0' && c <= '9' && imu_ok) {
            cp_clear();
            gesture_record_and_print(c - '0');
        }
        idle_tick(t++);
        vTaskDelay(pdMS_TO_TICKS(33));
    }
}

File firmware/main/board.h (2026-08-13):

// NeuralCard v2.3 pin map - extracted from the board netlist, do not guess.
#pragma once

// Charlieplex lines CP1..CP6 (through R1-R6, 220R)
#define PIN_CP1  4
#define PIN_CP2  5
#define PIN_CP3  6
#define PIN_CP4  7
#define PIN_CP5  15
#define PIN_CP6  16

// I2C bus shared by the IMU (U2) and the NFC chip's I2C side (U4)
#define PIN_SDA  8
#define PIN_SCL  17
#define I2C_PORT 0

// LSM6DS3TR-C, SA0 strapped high
#define LSM6DS3_ADDR 0x6B
#define PIN_IMU_INT  18

// ST25DV GPO (field-detect interrupt from a phone tap)
#define PIN_NFC_GPO  21

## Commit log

2026-08-13 clone NeuralCard for sponsorship
    [BOM_JLCPCB.csv, LCSC_order.csv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]
2026-08-13 add pcbway sourcing bom
    [BOM_PCBWay.csv]
2026-08-13 add part sourcing alternates
    [BOM_PCBWay.csv, NeuralCard.kicad_pcb, NeuralCard.kicad_sch]
2026-08-13 rename part libraries
    [NeuralCard.kicad_pcb, NeuralCard.kicad_sch]
2026-08-14 document reference schematic gaps
2026-08-14 document reference schematic check
2026-08-14 regenerate fab package
    [NeuralCard-B_Cu.gbl, NeuralCard-B_Mask.gbs, NeuralCard-B_Paste.gbp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]
